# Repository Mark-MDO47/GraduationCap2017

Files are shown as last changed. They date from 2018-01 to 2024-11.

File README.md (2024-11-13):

# GraduationCap2017
Graduation Cap Lights for my identical twin girls "I" and "T" - 2017-12-09<br>

**Table Of Contents**
* [Top](#graduationcap2017 "Top")
* [Photos and Videos](#photos-and-videos "Photos and Videos")
* [General Description](#general-description "General Description")
  * [Details of Design - Arduino Code](#details-of-design-\--arduino-code "Details of Design - Arduino Code")
  * [Details of Design - Schematics and etc.](#details-of-design-\--schematics-and-etc "Details of Design - Schematics and etc.")
  * [Details of Design - WS2812B LEDs](#details-of-design-\--ws2812b-leds "Details of Design - WS2812B LEDs")
  * [Details of Design - Keep the Wires Cool!](#details-of-design-\--keep-the-wires-cool "Details of Design - Keep the Wires Cool!")
  * [Details of Design - My Favorite Pullup Resistor Package](#details-of-design-\--my-favorite-pullup-resistor-package "Details of Design - My Favorite Pullup Resistor Package")

## Photos and Videos
[Top](#graduationcap2017 "Top")<br>
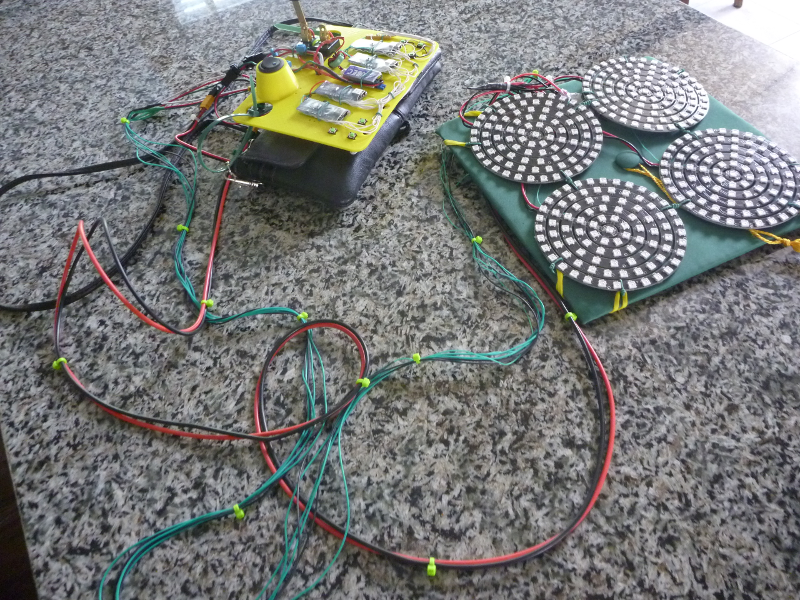
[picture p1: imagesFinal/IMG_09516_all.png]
Finished version of Graduation Cap; batteries inside purses

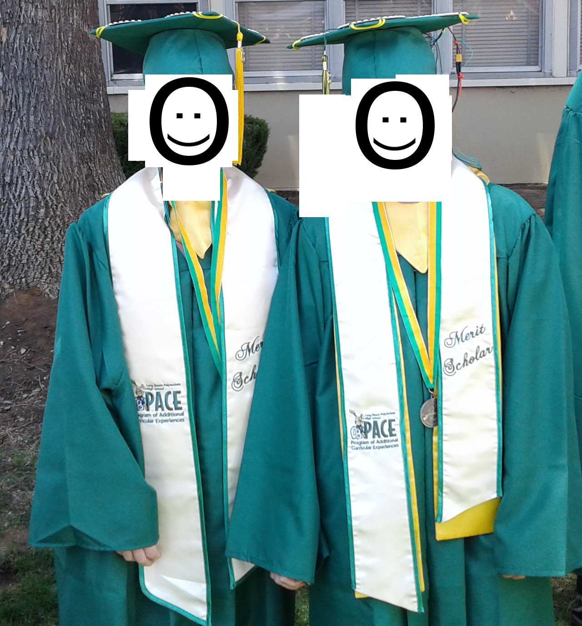
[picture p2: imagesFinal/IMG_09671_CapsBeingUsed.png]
Graduation Caps just before use


A few videos of the graduation cap:<br>
tour - https://youtu.be/3sHkcpifI_0 - Walkthrough of Graduation Cap<br>
Start plus the Down-the-Drain and Haunt patterns - https://youtu.be/SVAW7-W8W8M - my made-up patterns<br>
Radar - https://youtu.be/vZpsce-uMeo - my made-up pattern<br>
Circles - https://youtu.be/3rO7r-2uvlA - my made-up pattern<br>
Kriegsman Fire - https://youtu.be/K7lBy67Jgzw - Mark Kriegsman's Fire2012 with Palette<br>
Kriegsman Juggle - https://youtu.be/Ot5dQEGN8O8 - Mark Kriegsman's Juggle<br>
Kriegsman BPM - https://youtu.be/0liTM4aSAok - Mark Kriegsman's BPM<br>
Pictures and pointers to videos of Graduation cap are in the /FirstCap and imagesFinal directories<br>

## General Description
[Top](#graduationcap2017 "Top")<br>
The graduation cap electronics uses four Arduino Nanos with USB mini-B connector<br>
- example: https://www.aliexpress.us/item/2255800392785775.html ***Select Mini-USB Welding***<br>
  - V3.0 ATmega328P 5V 16M CH340 Compatible to Arduino Nano V3<br>
  - 32Kbyte Flash (program storage), 2Kbyte SRAM, 1Kbyte EEPROM<br>
  - http://www.mouser.com/pdfdocs/Gravitech_Arduino_Nano3_0.pdf<br>
  - http://www.pighixxx.com/test/pinouts/boards/nano.pdf<br>

Uses 93 Leds WS2812B 5050 RGB LED Ring Lamp Light with Integrated Drivers<br>
- https://www.amazon.com/WESIRI-WS2812B-Individually-Addressable-Controller/dp/B083W44B8N<br>

Kudos to Daniel Garcia and Mark Kriegsman for the FANTASTIC Arduino FastLED library and examples!!!<br>
  https://github.com/FastLED/FastLED<br>
  https://github.com/FastLED/FastLED/blob/master/examples<br>

The Arduino pattern code here is pretty much done from scratch by me using the FastLED library.<br>
I also tried a few items from Mark Kriegsman's classic DemoReel100.ino https://github.com/FastLED/FastLED/tree/master/examples/DemoReel100<br>
Okay, I succumbed and added in Mark's beautiful Fire2012withPalette https://github.com/FastLED/FastLED/tree/master/examples/Fire2012WithPalette<br>
At this point the patterns are about 50-50 mine and Mark Kriegsman<br>

### Details of Design - Arduino Code
[Top](#graduationcap2017 "Top")<br>
The Arduino code can be found here:<br>
https://github.com/Mark-MDO47/GraduationCap2017/tree/master/ArduinoCode/GradCap

### Details of Design - Schematics and etc.
[Top](#graduationcap2017 "Top")<br>
Schematic and other build information can be found here<br>
* https://github.com/Mark-MDO47/GraduationCap2017/blob/master/buildInfo/README.md

### Details of Design - WS2812B LEDs
[Top](#graduationcap2017 "Top")<br>
Here is a (somewhat) spec on the WS2812b LEDs<br>
  https://cdn-shop.adafruit.com/datasheets/WS2812B.pdf<br>
Here is a Worldsemi WS2812B document for download: <br>
  http://www.world-semi.com/solution/list-4-1.html#108<br>

### Details of Design - Keep the Wires Cool!
[Top](#graduationcap2017 "Top")<br>
Calculating wire size (Google for instance wire gauge ampacity 5v dc):<br>
  https://electronics.stackexchange.com/questions/148648/minimum-wire-gauge-for-5-volt-5-amp-system<br>

These LEDs use power that adds up. Can use this to estimate the power<br>

   http://fastled.io/docs/3.1/group___power.html<br>

     calculate_max_brightness_for_power_vmA(lots of parameters)
     
   https://github.com/FastLED/FastLED/blob/master/power_mgt.cpp<br>

     static const uint8_t gRed_mW   = 16 * 5; // 16mA @ 5v = 80mW
     static const uint8_t gGreen_mW = 11 * 5; // 11mA @ 5v = 55mW
     static const uint8_t gBlue_mW  = 15 * 5; // 15mA @ 5v = 75mW
     static const uint8_t gDark_mW  =  1 * 5; //  1mA @ 5v =  5mW
  
   about 42 milliamps per LED at max brightness WHITE<br>

### Details of Design - My Favorite Pullup Resistor Package
[Top](#graduationcap2017 "Top")<br>
Using DigiKey (https://digikey.com) 4610X-AP1-103LFCT-ND RES ARRAY 9 RES 10K OHM 10SIP<br>
   This way I have one component for all the 10K pull-up resistors I need<br>

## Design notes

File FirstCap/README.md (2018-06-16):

FirstGradCap.mp4 - video of cap with all four LED disks doing same pattern

LED_Disk_soldering.JPG            - how to wire the LED Disk<br>
LED_Disk_soldering_closeup.JPG    - how to wire the LED Disk - closeup<br>
GradCapWithDisks_FirstAttempt.JPG - start of putting the Cap together<br>

P1010498.JPG - start of wiring - finished 3 of 6 buttons - that is enough!!!<br>
P1010499.JPG - different view<br>
P1010500.JPG - different view<br>
<br>
P1010501.JPG - switch for LED power - uses 5.5Kohm to ground for internal light<br>
P1010502.JPG - detail of switch for LED power<br>
P1010503.JPG - added some connectors, made mistake for Arduino power-in (missed knife switch). Note attempting knots for strain relief.<br>
P1010506.JPG - all Arduinos wired & 3 buttons. Using cable tie for strain relief, color coded cable tie to identify connectors. Still error for Arduino power.<br>
P1010507.JPG - backside in process<br>
P1010508.JPG - starting on 2nd controller board, still have not noticed Arduino power error.<br>
P1010509.JPG - closeup 2nd controller board showing Arduino Nano soldering<br>
P1010510.JPG - closeup Arduino Nano soldering<br>
P1010511.JPG - closeup Arduino Nano soldering<br>
P1010512.JPG - closeup Arduino Nano soldering complete<br>
P1010513.JPG - closeup Arduino Nano soldering complete reverse side<br>

Videos of the graduation cap:<br>
tour  - https://youtu.be/3sHkcpifI_0 - Walkthrough of Graduation Cap<br>
Start plus the Down-the-Drain and Haunt patterns - https://youtu.be/SVAW7-W8W8M - my made-up patterns<br>
Radar - https://youtu.be/vZpsce-uMeo - my made-up pattern<br>
Circles - https://youtu.be/3rO7r-2uvlA - my made-up pattern<br>
Kriegsman Fire - https://youtu.be/K7lBy67Jgzw - Mark Kriegsman's Fire2012 with Palette<br>
Kriegsman Juggle - https://youtu.be/Ot5dQEGN8O8 - Mark Kriegsman's Juggle<br>
Kriegsman BPM - https://youtu.be/0liTM4aSAok - Mark Kriegsman's BPM<br>

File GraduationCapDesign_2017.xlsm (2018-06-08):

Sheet: CapDesign
Final

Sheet: PictureRing
Mokungit 93 Leds WS2812B WS2812 5050 RGB LED Ring Lamp Light with Integrated Drivers
https://smile.amazon.com/gp/product/B01EUAKLT0/ref=oh_aui_detailpage_o01_s00?ie=UTF8&psc=1
 | 2812b 5 volt
 | LED count | diameter
 | 32 | 110
 | 24 | 90
 | 16 | 70
 | 12 | 50
 | 8 | 30
 | 1 | N/A
 | 93 | total
 | Question: What are the dimensions of the rings?
 | Answer: My digital caliper says:
 | 32 led ring: 111.8 mm diameter
 | 24 led ring: 91.8 mm diameter… see more
 | ratio |  | part | 2 | 3 | 4 | 5 | 6 | 7 | 8
 | 4 to 3 | 8 to 6 |  | 16 | 10.66666667 | 8 | 6.4 | 5.333333333 | 4.571428571 | 4
 | 3 to 2 | 6 to 4 |  | 12 | 8 | 6 | 4.8 | 4 | 3.428571429 | 3
 |  | 4 to 3 |  | 8 | 5.333333333 | 4 | 3.2 | 2.666666667 | 2.285714286 | 2
 |  | 3 to 2 |  | 6 | 4 | 3 | 2.4 | 2 | 1.714285714 | 1.5
 |  |  |  | 4 | 2.666666667 | 2 | 1.6 | 1.333333333 | 1.142857143 | 1
 |  |  | outside-to-outside outer hole to diag outer hole |  |  |  | outside-to-outside outer hole to adjacent outer hole |  |  |  |  |  | hole diameter
 |  |  | 110.66 |  |  |  | 85.62 |  | 70.57 |  |  |  | 1.45
 |  |  | 110.45 |  |  |  | 86.01 |  | 70.83 |  |  |  | 1.54
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

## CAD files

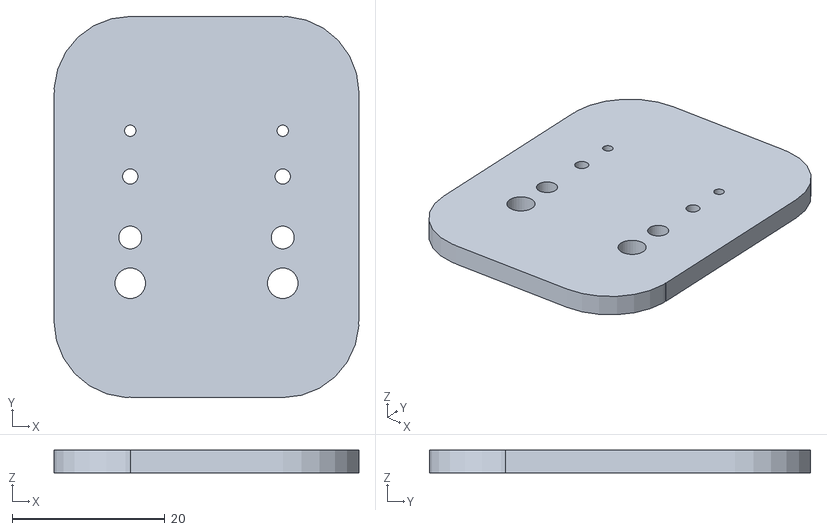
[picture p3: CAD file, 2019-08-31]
3D-Print/zzzTest.stl
40.0 x 50.0 x 3.00

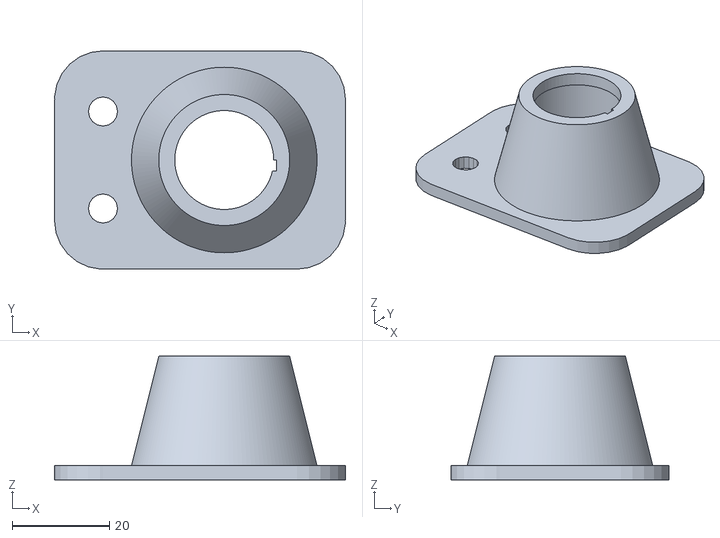
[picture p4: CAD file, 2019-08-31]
3D-Print/aaaTest.stl
60.0 x 45.0 x 25.5

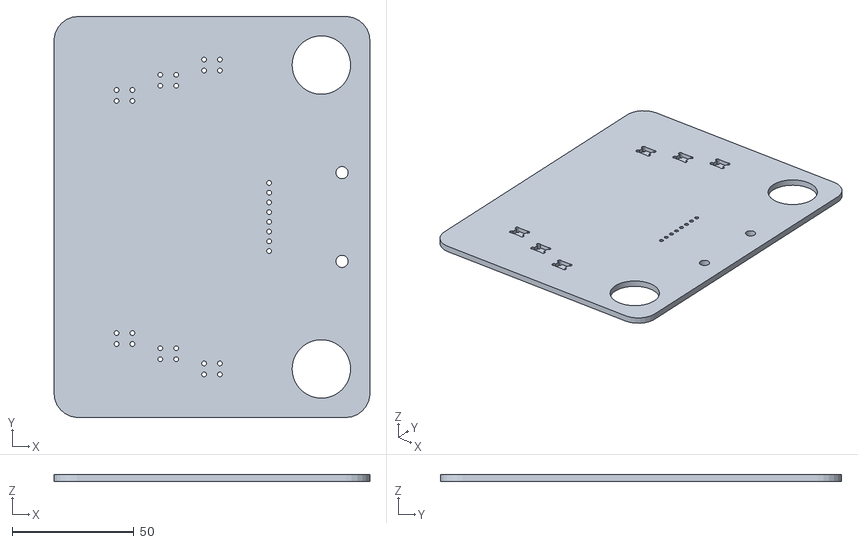
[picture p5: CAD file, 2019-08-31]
3D-Print/GradCapBracket.stl
130.0 x 165.0 x 3.00

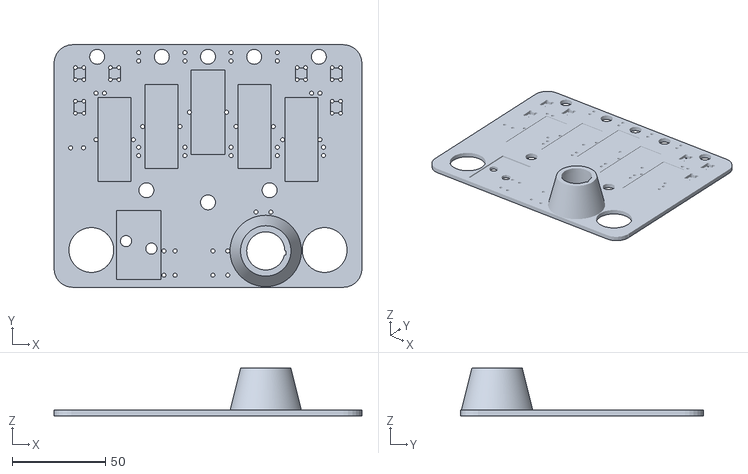
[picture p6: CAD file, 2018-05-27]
3D-Print/GradCapPurseHanger.stl
165.0 x 130.0 x 25.5

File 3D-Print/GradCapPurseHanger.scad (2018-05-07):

// Graduation Cap Lights for my identical twin girls high school graduation - 2017-12-09
// Mark Olson
// https://github.com/Mark-MDO47/GraduationCap2017
// 
// uses Mokungit 93 Leds WS2812B WS2812 5050 RGB LED Ring Lamp Light with Integrated Drivers
//   https://smile.amazon.com/gp/product/B01EUAKLT0/ref=oh_aui_detailpage_o01_s00?ie=UTF8&psc=1
// Kudos to Daniel Garcia and Mark Kriegsman for the FANTASTIC Arduino FastLED library and examples!!!
//   https://github.com/FastLED/FastLED
//   https://github.com/FastLED/FastLED/blob/master/examples/Fire2012WithPalette/Fire2012WithPalette.ino
// Some mods were made to the Arduino code by me to adapt to circular rings and also to add some patterns like spinners

// VERY handy routine from WarrantyVoider, published May 26, 2011
use<roundCornersCube.scad> // http://www.thingiverse.com/thing:8812

/*
    -----------------------------------------------------------
                 Round Corners Cube (Extruded)
      roundCornersCube(x,y,z,r) Where: (rounding done x and x corners)
         - x = Xdir width
         - y = Ydir width
         - z = Height of the cube
         - r = Rounding radius
      Example: roundCornerCube(10,10,2,1);
     *Some times it's needed to use F6 to see good results!
 	 -----------------------------------------------------------
*/
//
// This is the purse-hanger portion of the graduation cap project
//    The purse will carry the batteries, the purse-hanger has the
//    electronics, buttons, and connectors to the cables going to
//    the cap itself.
//
// I purse:  145 mm from strap-strap centerlines - 
//                straps <= 8 mm thick
//                about 190 mm horizontal
//                about 135 mm vertical
// T purse: 219 mm from strap-strap  - 8.6 inches
//                straps attached with metal D-ring
//                10 mm inner diameter D-ring
//                about 225 mm horizontal
//                about 110 mm vertical
//
// note: longest dimension on my table is 7 inches. 6.5 inches is about 165 millimeter

dsply_arduino = false;
color_arduino = "aqua";

dsply_ubec = false;
color_ubec = "red";

dsply_switch = false;
color_switch = "blue";

dsply_rsstr = false;
color_rsstr = "brown";

color_atch = "purple"; // wire attachment points

prjhngr_side  = 165; // from purse-strap to purse-strap
prjhngr_elect = 130; // width needed for electronics
prjhng_hook_width = 48; // hook stick width
prjhng_hook_length = 90; // hook stick length
prjhng_hook_inner_radius = 12; // hook

prjhng_hole_inner_radius = 12;
prjhng_hole_outer_radius = 20;

prjhng_thickness_frame = 3;
prjhng_thickness_cutout = 4;

// push buttons for choosing LED pattern
prjhng_btn_deep = prjhng_thickness_frame;
prjhng_btn_square = 6;
prjhng_btn_landing_long = 6.5;
prjhng_btn_landing_short = 4.5;
prjhng_btn_outer_long = 7.75; // includes bending of legs
// button location
prjhng_btn_fromside = (prjhngr_side/2-prjhng_hole_outer_radius);
prjhng_btn_fromhole = (prjhngr_elect/2-prjhng_hole_outer_radius);

// Arduino for controling LEDs
prjhngr_ardu_long   = 45;
prjhngr_ardu_short  = 17.6;
prjhngr_ardu_height = 4;
// arduino location
prjhngr_ardu_fromhole = -0.8*prjhngr_ardu_short;
prjhngr_ardu_fromhole_ary = [+1.0*prjhngr_ardu_fromhole, +1.5*prjhngr_ardu_fromhole, +1.5*prjhngr_ardu_fromhole, +1.0*prjhngr_ardu_fromhole];
prjhngr_ardu_fromside_ary = [-0.8*prjhng_btn_fromside, -0.4*prjhng_btn_fromside, +0.4*prjhng_btn_fromside, +0.8*prjhng_btn_fromside];

// UBEC for translating Arduino power
prjhngr_ubec_long   = 45.5;
prjhngr_ubec_short  = 18;
prjhngr_ubec_height = 4;
// arduino location
prjhngr_ubec_fromhole = -1.6*prjhngr_ubec_short;

// rocker power switch for LED power
// comments say need 13/16 inch hole or 0.8125 in or 20.6375 mm or 10.32 mm rad.
// manufacturer says "All you need is a 3/4" hole and the switch will sit in nicely"
//    0.75 in = 19.05 mm
// SparkFun says "They mount into a 20.2mm diameter hole"
// I measure 20.3 mm diam or 10.15 mm rad and that over a little knob it has
//   my measurement works quite well at 10.2
prjhngr_rokr_rad =       10.2;
prjhngr_rokr_height =    18.3;
prjhngr_rokr_lip_catch =  0.8;
prjhngr_rokr_lip_height = 2.4;
prjhngr_rokr_lip_rad =   11.5;
prjhngr_rokr_key_width =  2.3;
prjhngr_rokr_key_bump  =  0.6;
prjhngr_rokr_fromhole =   0.7*prjhngr_elect/2;
prjhngr_rokr_fromside =   0.375*prjhngr_side/2;
// rocker mount - to keep all high points on one side
prjhngr_rokrmnt_height = 24.0;
prjhngr_rokrmnt_btmrad = prjhngr_rokr_lip_rad+8;
prjhngr_rokrmnt_toprad = prjhngr_rokr_lip_rad+2;

// knife switch for arduino power
prjhngr_knif_outlong =         37.0; // y direction
prjhngr_knif_outshort =        24.0;
prjhngr_knif_outhigh =          7.5;
prjhngr_knif_ofsthol_short_s =  5.2;
prjhngr_knif_ofsthol_short_l = 18.8;
prjhngr_knif_ofsthol_long_s =  16.5;
prjhngr_knif_ofsthol_long_l =  20.5;
prjhngr_knif_cntrhol_short_s = 12.0;
prjhngr_knif_cntrhol_short_l = 12.0;
prjhngr_knif_cntrhol_long_s =   8.1;
prjhngr_knif_cntrhol_long_l =  28.9;
prjhngr_knif_knob_ovrhng =     13.7;
prjhngr_knif_knob_width =       4.7;
prjhngr_knif_fromhole =   0.65*prjhngr_elect/2;
prjhngr_knif_fromside =   0.45*prjhngr_side/2;
// holes for potential screws for knife switch
prjhngr_knif_ofsthol_rad = 3.0; // this works for ziptie attachment too
prjhngr_knif_cntrhol_rad = 3.0;
prjhngr_knif_ofsthol =  true;
prjhngr_knif_cntrhol =  false;

// 10K pullup multi-resistor
prjhngr_rsstr_short =     4.9;
prjhngr_rsstr_long =     25.2;
prjhngr_rsstr_high =      2.2;
prjhngr_rsstr_fromhole = -0.15*prjhngr_elect/2;
prjhngr_rsstr_fromside =  -0.85*prjhngr_side/2;

// wiring attachment points - width
prjhngr_atch_pwrled_short  = 6.0; // both LED power (under) and Arduino data lines (over)
prjhngr_atch_pwrled_fromhole_ary = [0.9*prjhngr_elect/2, 0.7*prjhngr_elect/2, 0.38*prjhngr_elect/2];
prjhngr_atch_pwrled_fromside_ary = [0.08*prjhngr_side/2, 0.08*prjhngr_side/2, 0.36*prjhngr_side/2];
prjhngr_atch_pwrardu_short = 4.0;
prjhngr_atch_pwrardu_fromhole_ary = [0.9*prjhngr_elect/2,  0.7*prjhngr_elect/2];
prjhngr_atch_pwrardu_fromside_ary = [-0.25*prjhngr_side/2, -0.25*prjhngr_side/2];
prjhngr_atch_sgnlgnd_short = 2.5;
prjhngr_sgnlgnd_bus1_fromhole = -0.12*prjhngr_elect/2; // bus 1 is in middle of board
prjhngr_sgnlgnd_bus2_fromhole = -0.90*prjhngr_elect/2; // bus 2 is near bottom of board
prjhngr_atch_sgnlgnd_fromhole_ary = [-0.60*prjhngr_elect/2, -0.60*prjhngr_elect/2,
    prjhngr_sgnlgnd_bus1_fromhole, prjhngr_sgnlgnd_bus1_fromhole,
    prjhngr_sgnlgnd_bus1_fromhole, prjhngr_sgnlgnd_bus1_fromhole, prjhngr_sgnlgnd_bus1_fromhole,
    prjhngr_sgnlgnd_bus2_fromhole, prjhngr_sgnlgnd_bus2_fromhole,
    prjhngr_sgnlgnd_bus2_fromhole, prjhngr_sgnlgnd_bus2_fromhole];
prjhngr_atch_sgnlgnd_fromside_ary = [-0.70*prjhngr_side/2,  +0.70*prjhngr_side/2,
    -0.45*prjhngr_side/2, -0.15*prjhngr_side/2,
    +0.15*prjhngr_side/2, +0.45*prjhngr_side/2, +0.75*prjhngr_side/2,
    -0.45*prjhngr_side/2, -0.15*prjhngr_side/2,
    +0.15*prjhngr_side/2, +0.45*prjhngr_side/2];

prjhngr_thruwire_rad = 4;
prjhngr_thruwire_fromhole_ary = [+0.30*prjhngr_elect/2, -0.90*prjhngr_elect/2,
    -0.90*prjhngr_elect/2, -0.90*prjhngr_elect/2,
    -0.90*prjhngr_elect/2, -0.90*prjhngr_elect/2,
    +0.20*prjhngr_elect/2, +0.20*prjhngr_elect/2];
prjhngr_thruwire_fromside_ary = [ 0, 0,
    -0.72*prjhngr_side/2,  +0.72*prjhngr_side/2,
    -0.30*prjhngr_side/2,  +0.30*prjhngr_side/2,
    -0.4*prjhngr_side/2,  +0.4*prjhngr_side/2];
prjhngr_ziptie_rad = 1.1; // 3 allows actual zip-tie, 1.1 just barely fits wire

module aaaTest() { // aaaTest - test of holes for rokr and ziptie
    rotate ([0,0,-90]) difference() {
        union() {
            roundCornersCube(45,60,3, 10);
            translate([0,5,0]) prjhngr_rokrmnt();
        } // end union()
        //translate([0,5,-prjhngr_rokrmnt_height/2]) prjhngr_rokr(200);
        translate([0,5,-5]) color("green")translate([0,0,+(prjhngr_rokrmnt_height-prjhng_thickness_frame)/2])linear_extrude(height = prjhngr_rokrmnt_height-prjhng_thickness_frame, center = true, convexity = 0, twist = 0, slices = 100, scale = 1.0) circle(r=prjhngr_rokr_lip_rad,$fn=128);
        translate([+10,-20,0]) prjhngr_ziptiehole();
        translate([-10,-20,0]) prjhngr_ziptiehole();
    } // end difference()
}

module bbbTest() { // bbbTest - test of holes for knife switch
    rotate ([0,0,-90]) union() {
        difference() {
            roundCornersCube(50,40,3, 10);
            translate([0,0,-1]) prjhngr_knif();
            prjhngr_knif_holes();
        } // end union
        //prjhngr_knif();
    } // end difference
}  // end bbbTest()

module cccTest() { // cccTest - test of 10k pullup resistor and mounting holes
    rotate ([0,0,-90]) union() {
        difference() {
            roundCornersCube(50,40,3, 10);
            prjhngr_rsstr_holes();
        } // end union
        if (dsply_rsstr) prjhngr_rsstr();
    } // end difference
}  // end bbbTest()
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

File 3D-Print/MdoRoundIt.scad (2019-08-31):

module MdoRoundItOnXaxis(dim_long, hole_diam, square_width)
{
    difference() {
        translate([-dim_long/2, -square_width/2, -square_width/2]) cube([dim_long, square_width, square_width]);
        rotate([0, 90, 0]) translate([0, 0, -(dim_long+2)/2])cylinder(r=hole_diam/2,h=dim_long+2,$fn=128);
        translate([-dim_long/2-1, -square_width/2-1, -square_width-2]) cube([dim_long+2, square_width+2, square_width+2]);
    }
}   // end MdoRoundItOnXaxis()

MdoRoundItOnXaxis(100,10,15);

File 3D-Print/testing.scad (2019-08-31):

// VERY handy routine from WarrantyVoider, published May 26, 2011
use<roundCornersCube.scad> // http://www.thingiverse.com/thing:8812


kstn_jack_stretch = 0.75; // MDO mod: my keystone jacks are slightly larger or maybe my printer is different; cannot jam jacks in without some stretch

kstn_jack_length = 16.5;
kstn_jack_width = 15;

kstn_wall_height = 10;
kstn_wall_thickness = 5;

kstn_catch_overhang = 2;

kstn_small_clip_depth = kstn_catch_overhang;
kstn_big_clip_depth = kstn_catch_overhang + 2;
kstn_big_clip_clearance = 4;
kstn_small_clip_clearance = 6.5;

// MDO mod: add kstn_jack_stretch to length for my slightly larger keystone jacks
kstn_outer_length = kstn_jack_length + kstn_small_clip_depth + kstn_big_clip_depth +
                            (kstn_wall_thickness * 2) + kstn_jack_stretch;
kstn_outer_width = kstn_jack_width + (kstn_wall_thickness * 2);



// roundCornersCube(kstn_outer_length, kstn_outer_width, kstn_wall_height,2);
cube([kstn_outer_length, kstn_outer_width, kstn_wall_height]);

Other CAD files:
3D-Print/bbbTest.stl
3D-Print/roundCornersCube.scad

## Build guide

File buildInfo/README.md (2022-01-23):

# Build Info README

## Schematic

Schematic for Graduation Cap<br>
* https://github.com/Mark-MDO47/GraduationCap2017/blob/master/buildInfo/Schematic_4_Arduinos.pdf

## Signal Tracing for 4 Arduinos/LEDrings

Top view of Cap showing placement of LED Rings
* https://github.com/Mark-MDO47/GraduationCap2017/blob/master/buildInfo/CapTopView.png

Annotated photo of controller board identifying Arduino controlling each LED ring
* https://github.com/Mark-MDO47/GraduationCap2017/blob/master/buildInfo/ControllerIdentifySignal.png

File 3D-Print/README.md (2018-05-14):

NOTE:

Due to major project simplifications, the only 3D print I am using is GradCapPurseHanger.scad

Thanks!
Mark

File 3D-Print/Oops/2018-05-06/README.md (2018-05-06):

When print started there was a slight mis-registration between the first raft outline layer and the next.
It looked to be on track after that and was still looking good a few hours later.
After about 8 hours it showed signs of warping up off the bed from one corner that was hanging off the first raft outline layer (in the air)
Next morning it was a disaster.
 The raft and start of the print were pushed off the bed.
 The printer hot end was still spewing and was completely coated with plastic.
 Even the wires to the hot end were encapsulated.
 477 thru 479

Fortunately when I heated up to pull the filament out the encapsulation was brittle.
  Small manipulations made pieces that could pull off with needle-nose.
  Even the plastic around the wires came apart, though I was worried.
  484 thru 485

Additional cleanup makes it look almost like before. Will have to see if it works
  489 thru 491

The partial print was usable to do a fit-check of some parts.
  493 thru 495

Hmm - comment of "that doesn't look good!!!" gets turned by bash into "that doesn't look goodgit status!".
A bit of an information leak there... not too bad this time.

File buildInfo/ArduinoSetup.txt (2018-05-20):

Arduino Uno  - Board "Arduino/Genuino Uno"
Arduino Nano - Board "Arduino Nano"  - use Old Bootloader

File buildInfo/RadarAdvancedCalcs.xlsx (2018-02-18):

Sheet: Sheet1
const uint8_t leds_per_ring[NUM_RINGS_PER_DISK] = { 32, 24, 16, 12, 8, 1 };
const uint8_t leds_per_ringqrtr[NUM_RINGS_PER_DISK] = { 8, 6, 4, 3, 2, 1 };
const uint8_t start_per_ring[NUM_RINGS_PER_DISK] = { 0, 32, 56, 72, 84, 92 };
const uint8_t radar_adv_per_LED_per_ring[NUM_RINGS_PER_DISK] = { 0, 192, 128, 96, 64, 0 };
 |  |  |  |  | tmp_calc for this_ring |  |  |  | theLED for this ring |  |  |  | 2nd tmp_calc for this_ring
 | tmp_idx | radar_adv_per_LED_per_ring | start_per_ring | leds_per_ring | 1 | 2 | 3 | 4 | 1 | 2 | 3 | 4 | 1 | 2 | 3 | 4
 | 0 | 0 | 0 | 32 | 0 | 0 | 0 | 0 | 32 | 56 | 72 | 84 | 55 | 71 | 83 | 91
 | 1 | 192 | 32 | 24 | 0 | 0 | 0 | 0 | 32 | 56 | 72 | 84 | 55 | 71 | 83 | 91
 | 2 | 128 | 56 | 16 | 1 | 1 | 0 | 0 | 33 | 57 | 72 | 84 | 32 | 56 | 83 | 91
 | 3 | 96 | 72 | 12 | 2 | 1 | 1 | 0 | 34 | 57 | 73 | 84 | 33 | 56 | 72 | 91
 | 4 | 64 | 84 | 8 | 3 | 2 | 1 | 1 | 35 | 58 | 73 | 85 | 34 | 57 | 72 | 84
 | 5 | 0 | 92 | 1 | 3 | 2 | 1 | 1 | 35 | 58 | 73 | 85 | 34 | 57 | 72 | 84
 | 6 |  |  |  | 4 | 3 | 2 | 1 | 36 | 59 | 74 | 85 | 35 | 58 | 73 | 84
 | 7 |  |  |  | 5 | 3 | 2 | 1 | 37 | 59 | 74 | 85 | 36 | 58 | 73 | 84
 | 8 |  |  |  | 6 | 4 | 3 | 2 | 38 | 60 | 75 | 86 | 37 | 59 | 74 | 85
 | 9 |  |  |  | 6 | 4 | 3 | 2 | 38 | 60 | 75 | 86 | 37 | 59 | 74 | 85
 | 10 |  |  |  | 7 | 5 | 3 | 2 | 39 | 61 | 75 | 86 | 38 | 60 | 74 | 85
 | 11 |  |  |  | 8 | 5 | 4 | 2 | 40 | 61 | 76 | 86 | 39 | 60 | 75 | 85
 | 12 |  |  |  | 9 | 6 | 4 | 3 | 41 | 62 | 76 | 87 | 40 | 61 | 75 | 86
 | 13 |  |  |  | 9 | 6 | 4 | 3 | 41 | 62 | 76 | 87 | 40 | 61 | 75 | 86
 | 14 |  |  |  | 10 | 7 | 5 | 3 | 42 | 63 | 77 | 87 | 41 | 62 | 76 | 86
 | 15 |  |  |  | 11 | 7 | 5 | 3 | 43 | 63 | 77 | 87 | 42 | 62 | 76 | 86
 | 16 |  |  |  | 12 | 8 | 6 | 4 | 44 | 64 | 78 | 88 | 43 | 63 | 77 | 87
 | 17 |  |  |  | 12 | 8 | 6 | 4 | 44 | 64 | 78 | 88 | 43 | 63 | 77 | 87
 | 18 |  |  |  | 13 | 9 | 6 | 4 | 45 | 65 | 78 | 88 | 44 | 64 | 77 | 87
 | 19 |  |  |  | 14 | 9 | 7 | 4 | 46 | 65 | 79 | 88 | 45 | 64 | 78 | 87
 | 20 |  |  |  | 15 | 10 | 7 | 5 | 47 | 66 | 79 | 89 | 46 | 65 | 78 | 88
 | 21 |  |  |  | 15 | 10 | 7 | 5 | 47 | 66 | 79 | 89 | 46 | 65 | 78 | 88
 | 22 |  |  |  | 16 | 11 | 8 | 5 | 48 | 67 | 80 | 89 | 47 | 66 | 79 | 88
 | 23 |  |  |  | 17 | 11 | 8 | 5 | 49 | 67 | 80 | 89 | 48 | 66 | 79 | 88
 | 24 |  |  |  | 18 | 12 | 9 | 6 | 50 | 68 | 81 | 90 | 49 | 67 | 80 | 89
 | 25 |  |  |  | 18 | 12 | 9 | 6 | 50 | 68 | 81 | 90 | 49 | 67 | 80 | 89
 | 26 |  |  |  | 19 | 13 | 9 | 6 | 51 | 69 | 81 | 90 | 50 | 68 | 80 | 89
 | 27 |  |  |  | 20 | 13 | 10 | 6 | 52 | 69 | 82 | 90 | 51 | 68 | 81 | 89
 | 28 |  |  |  | 21 | 14 | 10 | 7 | 53 | 70 | 82 | 91 | 52 | 69 | 81 | 90
 | 29 |  |  |  | 21 | 14 | 10 | 7 | 53 | 70 | 82 | 91 | 52 | 69 | 81 | 90
 | 30 |  |  |  | 22 | 15 | 11 | 7 | 54 | 71 | 83 | 91 | 53 | 70 | 82 | 90
 | 31 |  |  |  | 23 | 15 | 11 | 7 | 55 | 71 | 83 | 91 | 54 | 70 | 82 | 90
sed "s/, /\$\$\$\$ /g" GradCap.ino | sed "s/^ /,/" | sed "s/, /,,/" | sed "s/, /,,/" | sed "s/, /,,/" | sed "s/, /,,/" | sed "s/, /,,/" | sed "s/, /,,/" > mdo.csv
else if ((STEP2_RADAR_FROM_SHDW1 == this_ptrn_token) || (STEP2_RADAR_XRAY_SHDW1 == this_ptrn_token)) {
 | uint16_t tmp_calc;
 | DEBUG_PRINTLN(F(" ...processing STEP2_RADAR_FROM_SHDW1 and friends; this_ptrn_token: "))
 | DEBUG_PRINT((int16_t) this_ptrn_token)
 | if (STEP2_RADAR_FROM_SHDW1 == this_ptrn_token) { // clear radar_xray_bitmask
 |  | radar_xray_bitmask[0] = radar_xray_bitmask[1] = radar_xray_bitmask[2] = 0;
 | } // end if need to clear bitmask for X-Ray cells
 | DEBUG_PRINTLN(F(" ... Radar Loop"))
 | for (tmp_idx = 0; tmp_idx < leds_per_ring[0]; tmp_idx++) {
 |  | // tmp_idx is the LED index on the outer ring, from 0 to 31 inclusive
 |  | // STEP2_RADAR_XRAY_SHDW1 X-Ray foreground color; STEP2_RADAR_FROM_SHDW1 does not
 |  | // First we fade previously drawn LEDs.
 |  | // If STEP2_RADAR_FROM_SHDW1: they all fade uniformly because we cleared radar_xray_bitmask
 |  | // If STEP2_RADAR_XRAY_SHDW1: the X-ray LEDs fade slower than the others
 |  | bitmsk32 = 1; // used to pick bit within radar_xray_bitmask
 |  | idx_bitmsk32 = 0; // location in radar_xray_bitmask
 |  | for (theLED = 0; theLED < NUM_LEDS_PER_DISK; theLED++){
 |  |  | if (0 != (radar_xray_bitmask[idx_bitmsk32] & bitmsk32)) { led_display[TARGET_DSPLAY+theLED].fadeToBlackBy(32); }
 |  |  | else { led_display[TARGET_DSPLAY+theLED].fadeToBlackBy(128); }
 |  |  | bitmsk32 <<= 1;
 |  |  | if (0 == bitmsk32) {
 |  |  |  | idx_bitmsk32 += 1;
 |  |  |  | bitmsk32 = 1;
 |  |  | } // end if need to cross bitmsk32 boundary
 |  | } // end loop to fade all previously drawn LEDs
 |  | // Next we draw the red line using the outer LED as a guide.
 |  | // For each ring (except center) we put a version of what was in SHDW1 previous to the red line we just drew.
 |  | // Outer and center rings are the simplest cases; do them first
 |  | led_display[TARGET_DSPLAY+NUM_LEDS_PER_DISK-1] = CRGB::Red; // center special case - no "previous" LED
 |  | led_display[TARGET_DSPLAY+tmp_idx] = CRGB::Red; // outer ring
 |  | theLED = (tmp_idx + leds_per_ring[0] - 1) % leds_per_ring[0]; // outer ring previous LED
 |  | led_display[TARGET_DSPLAY+theLED] = led_display[TARGET_SHDW1+theLED]; // outer ring copy from SHDW1
 |  | // Red line for Outer and Center are drawn; now handle middle rings
 |  | for (this_ring = 1; this_ring < NUM_RINGS_PER_DISK-1; this_ring++) {
 |  |  | // currently we do a trailing inner ring based on first LED that would have any fractional brightness
 |  |  | // first draw the red line of the radar sweep
 |  |  | tmp_calc = (uint16_t)radar_adv_per_LED_per_ring[this_ring] * tmp_idx / 256; // not same as above - / 256
 |  |  | theLED = tmp_calc + start_per_ring[this_ring]; // this is the lowest LED idx this ring
 |  |  | led_display[TARGET_DSPLAY+theLED] = CRGB::Red;
 |  |  | // now draw just behind it (where previous red line was) with contents of shadow1
 |  |  | // inner rings move slower so we start them at a lower light level using blend
 |  |  | tmp_calc = (tmp_calc + leds_per_ring[this_ring] - 1) % leds_per_ring[this_ring] + start_per_ring[this_ring]; // backup one LED
 |  |  | led_display[TARGET_DSPLAY+tmp_calc] = blend(CRGB::Black, led_display[TARGET_SHDW1+tmp_calc], leds_per_ring[this_ring]*7); // 32 leds * 8 would be 256 but our largest is 24 so no need for uint16_t
 |  | } // end RADAR for this_ring
 |  | if (doPtrnShowDwell(draw_target | led_delay | __LINE__)) return(__LINE__);
 | } // end RADAR for LED idx outer disk
} // end STEP2_RADAR_FROM_SHDW1 or STEP2_RADAR_XRAY_SHDW1 for LED idx outer disk

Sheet: Sheet2
else if ((STEP2_RADAR_FROM_SHDW1 == this_ptrn_token) || (STEP2_RADAR_FROM_SHDW1_FRGND == this_ptrn_token)) {
uint16_t tmp_calc;
DEBUG_PRINTLN(F(" ...processing STEP2_RADAR_FROM_SHDW1 and friends; this_ptrn_token: "))
DEBUG_PRINT((int16_t) this_ptrn_token)
if (STEP2_RADAR_FROM_SHDW1_FRGND == this_ptrn_token) {
DEBUG_PRINTLN(F(" ... X-Ray Exploration Loop"))
// set a bit for each cell we will "X-Ray" or fade slower
radar_xray_bitmask[0] = radar_xray_bitmask[1] = radar_xray_bitmask[2] = 0;
bitmsk32 = 1; // used to pick bit within radar_xray_bitmask
idx_bitmsk32 = 0; // location in radar_xray_bitmask
for (theLED = 0; theLED < NUM_LEDS_PER_DISK; theLED++){
if (led_display[TARGET_SHDW1+theLED] == foreground) { radar_xray_bitmask[idx_bitmsk32] |= bitmsk32; }
bitmsk32 <<= 1;
if (0 == bitmsk32) {
idx_bitmsk32 += 1;
bitmsk32 = 1;
if (idx_bitmsk32 > 2) { // should never get here
DEBUG_ERRORS_PRINTLN(F(" OVERFLOW ERROR IN STEP2_RADAR_FROM_SHDW1_FRGND loop to make bitmask for X-Ray cells"))
return(__LINE__);
} // end if something went horribly wrong
} // end if need to cross bitmsk32 boundary
// if ((0 == theLED) || ((29 <= theLED) && (34 > theLED))) { DEBUG_ERRORS_PRINT(F(" bitmsk32 info post increment. theLED=")) DEBUG_ERRORS_PRINT((uint16_t) theLED) DEBUG_ERRORS_PRINT(F(" idx_bitmsk32=")) DEBUG_ERRORS_PRINT((uint16_t) idx_bitmsk32) DEBUG_ERRORS_PRINT(F(" bitmsk32=")) DEBUG_ERRORS_PRINTLN((uint32_t) bitmsk32) } // end if debugging bitmask
} // end loop to make bitmask for X-Ray cells
// DEBUG_ERRORS_PRINT(F(" bitmsk32[0]=")) DEBUG_ERRORS_PRINT((uint32_t) radar_xray_bitmask[0]) DEBUG_ERRORS_PRINT(F(" bitmsk32[1]=")) DEBUG_ERRORS_PRINT((uint32_t) radar_xray_bitmask[1]) DEBUG_ERRORS_PRINT(F(" bitmsk32[2]=")) DEBUG_ERRORS_PRINTLN((uint32_t) radar_xray_bitmask[2])
} // end if need to make bitmask for X-Ray cells
DEBUG_PRINTLN(F(" ... Radar Loop"))
for (tmp_idx = 0; tmp_idx < leds_per_ring[0]; tmp_idx++) {
// tmp_idx is the LED index on the outer ring, from 0 to 31 inclusive
// STEP2_RADAR_FROM_SHDW1_FRGND X-Ray foreground color; STEP2_RADAR_FROM_SHDW1 does not
if (STEP2_RADAR_FROM_SHDW1 == this_ptrn_token) {
fadeToBlackBy(&led_display[TARGET_DSPLAY], NUM_LEDS_PER_DISK, 128); // last param is fade by x/256
} // end if STEP2_RADAR_FROM_SHDW1
else { // STEP2_RADAR_FROM_SHDW1_FRGND
bitmsk32 = 1; // used to pick bit within radar_xray_bitmask
idx_bitmsk32 = 0; // location in radar_xray_bitmask
for (theLED = 0; theLED < NUM_LEDS_PER_DISK; theLED++){
if (0 != (radar_xray_bitmask[idx_bitmsk32] & bitmsk32)) { led_display[TARGET_DSPLAY+theLED].fadeToBlackBy(8); } // DEBUG_ERRORS_PRINT(F(" prsrvLED=")) DEBUG_ERRORS_PRINT((uint16_t) theLED) DEBUG_ERRORS_PRINT(F(" idx_bitmsk32=")) DEBUG_ERRORS_PRINT((uint16_t) idx_bitmsk32) DEBUG_ERRORS_PRINT(F(" bitmsk32=")) DEBUG_ERRORS_PRINT((uint32_t) bitmsk32)}
else { led_display[TARGET_DSPLAY+theLED].fadeToBlackBy(128); }
bitmsk32 <<= 1;
if (0 == bitmsk32) {
idx_bitmsk32 += 1;
bitmsk32 = 1;
if (idx_bitmsk32 > 2) { // should never get here
DEBUG_ERRORS_PRINTLN(F(" OVERFLOW ERROR IN STEP2_RADAR_FROM_SHDW1_FRGND loop to use X-Ray cells"))
return(__LINE__);
} // end if something went horribly wrong
} // end if need to cross bitmsk32 boundary
} // end loop to make bitmask for X-Ray cells
} // end if STEP2_RADAR_FROM_SHDW1_FRGND
led_display[TARGET_DSPLAY+NUM_LEDS_PER_DISK-1] = CRGB::Red; // center
led_display[TARGET_DSPLAY+tmp_idx] = CRGB::Red; // outer ring
theLED = (tmp_idx + leds_per_ring[0] - 1) % leds_per_ring[0]; // backup one LED
led_display[TARGET_DSPLAY+theLED] = led_display[TARGET_SHDW1+theLED];
for (this_ring = 1; this_ring < NUM_RINGS_PER_DISK-1; this_ring++) {
// currently we do a trailing inner ring based on first LED that would have any fractional brightness
// first draw the red line of the radar sweep
tmp_calc = (uint16_t)radar_adv_per_LED_per_ring[this_ring] * tmp_idx / 256; // not same as above - / 256
theLED = tmp_calc + start_per_ring[this_ring]; // this is the lowest LED idx this ring
led_display[TARGET_DSPLAY+theLED] = CRGB::Red;
// now draw just behind it (where previous red line was) with contents of shadow1
// inner rings move slower so we start them at a lower light level using blend
tmp_calc = (tmp_calc + leds_per_ring[this_ring] - 1) % leds_per_ring[this_ring] + start_per_ring[this_ring]; // backup one LED
led_display[TARGET_DSPLAY+tmp_calc] = blend(CRGB::Black, led_display[TARGET_SHDW1+tmp_calc], leds_per_ring[this_ring]*7); // 32 leds * 8 would be 256 but our largest is 24 so no need for uint16_t
} // end RADAR for this_ring
if (doPtrnShowDwell(draw_target,led_delay,__LINE__)) return(__LINE__);
} // end RADAR for LED idx outer disk
} // end STEP2_RADAR_FROM_SHDW1 for LED idx outer disk

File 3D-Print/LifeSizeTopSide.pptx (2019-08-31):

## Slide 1

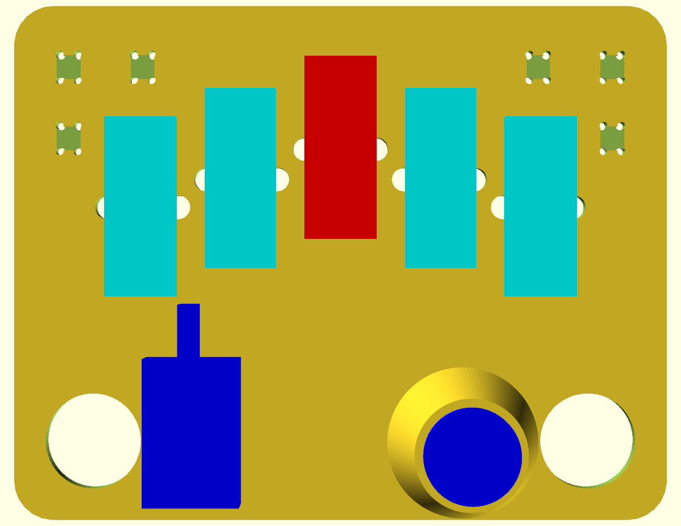
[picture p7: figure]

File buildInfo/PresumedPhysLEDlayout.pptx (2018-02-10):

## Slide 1

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
Phys

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
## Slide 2

Phys

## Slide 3

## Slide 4

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
Phys

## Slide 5

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
Phys

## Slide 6

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
Phys

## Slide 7

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
Phys

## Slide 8

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
Phys

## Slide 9

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
Phys

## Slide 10

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
Phys

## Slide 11

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
Phys

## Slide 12

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
Phys

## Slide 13

SPARE

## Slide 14

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
Phys

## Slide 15

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
Phys

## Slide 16

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
Phys

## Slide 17

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
Phys

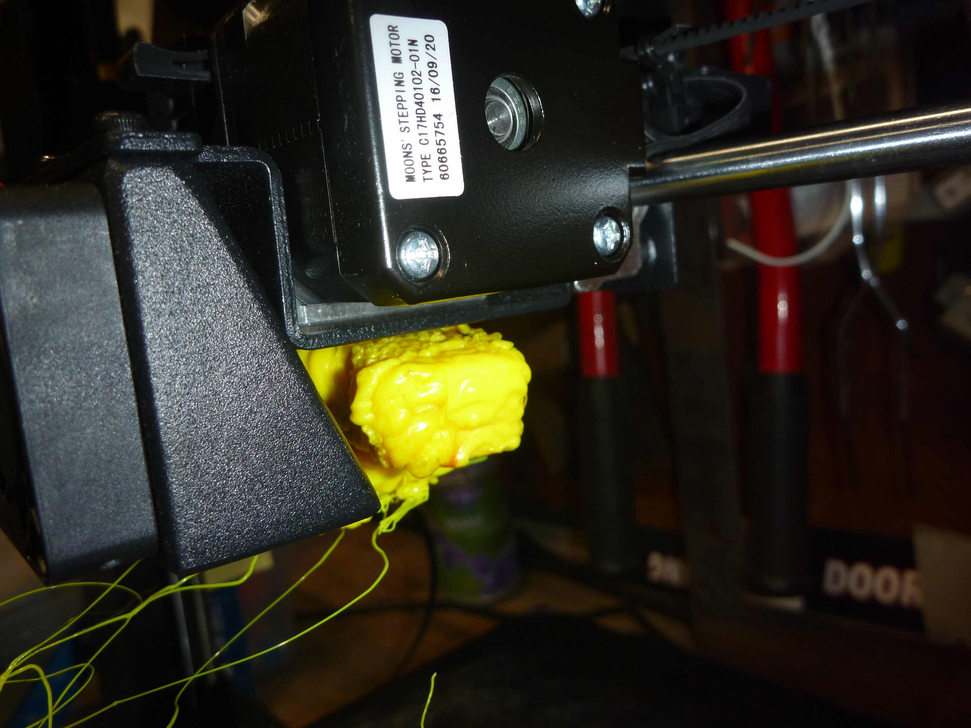
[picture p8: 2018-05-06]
3D-Print/Oops/2018-05-06/P1010479.JPG

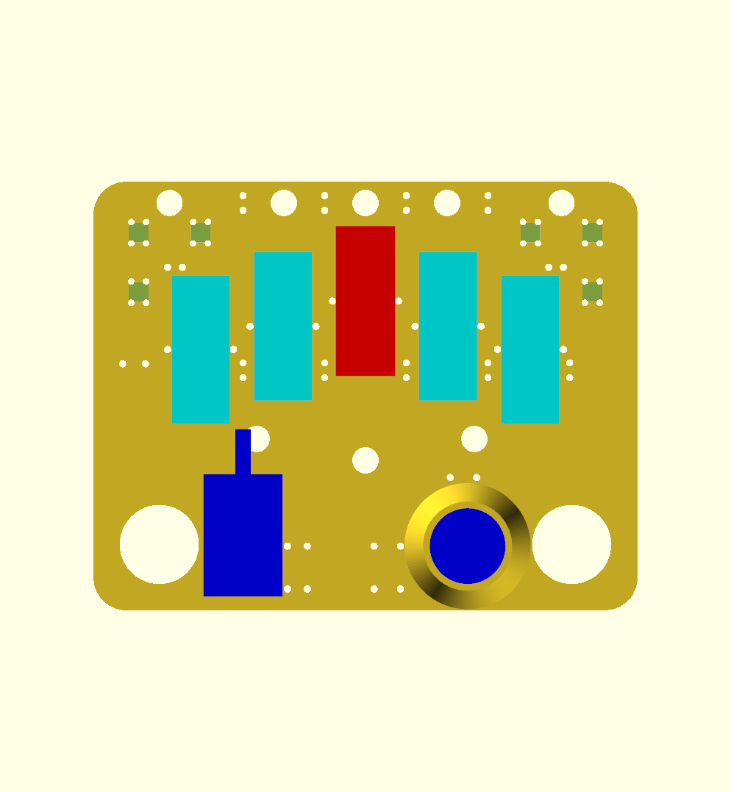
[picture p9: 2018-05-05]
3D-Print/GradCapPurseHanger_2D.png

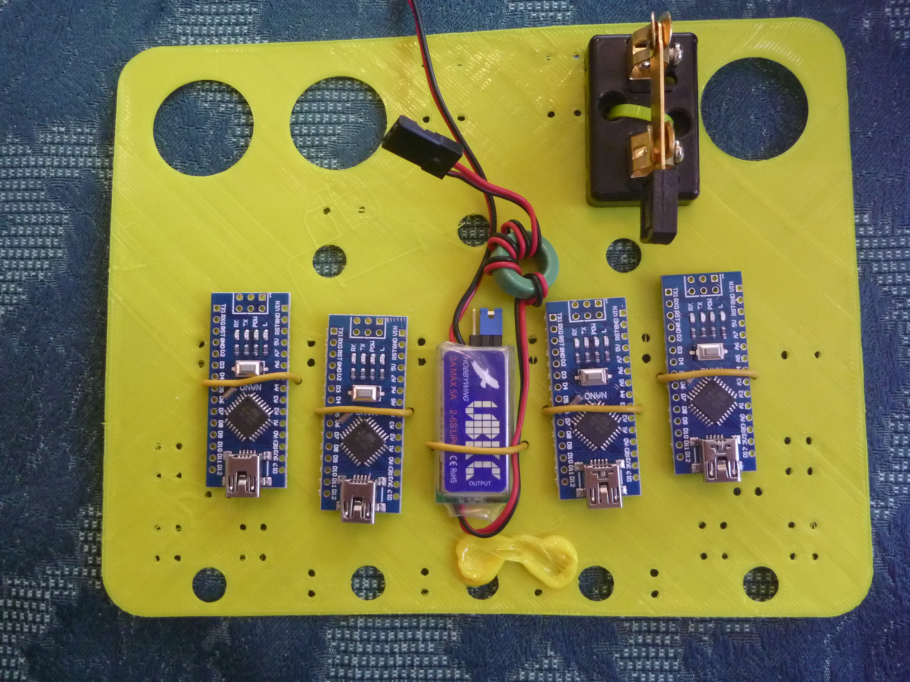
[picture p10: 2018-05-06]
3D-Print/Oops/2018-05-06/P1010494.JPG

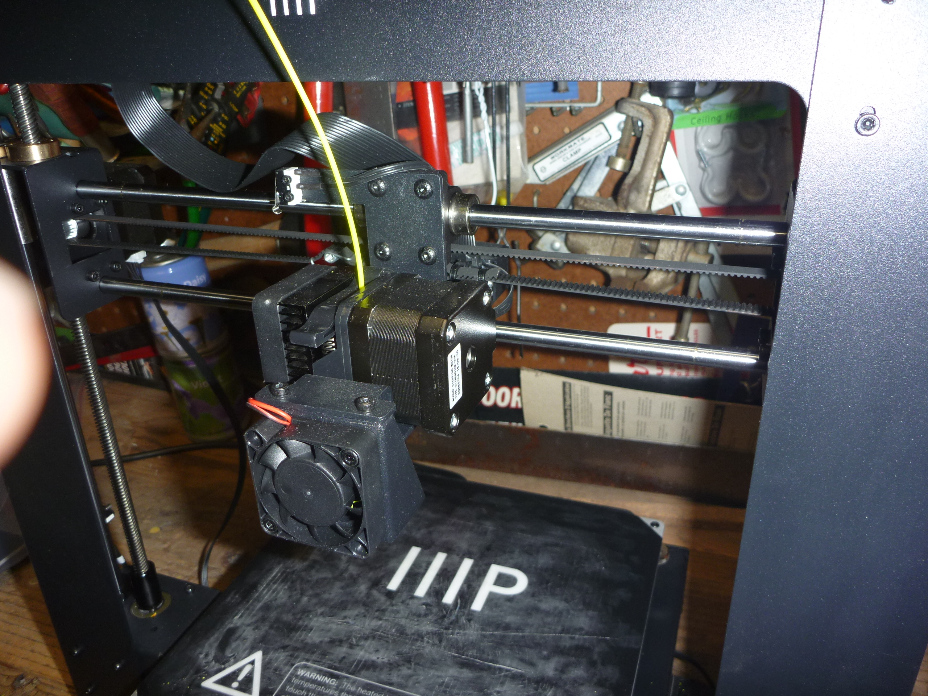
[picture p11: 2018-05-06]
3D-Print/Oops/2018-05-06/P1010491.JPG

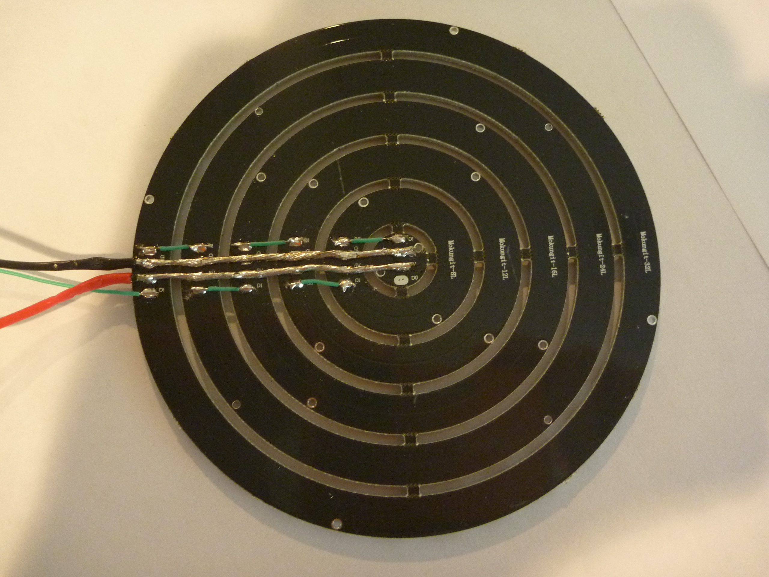
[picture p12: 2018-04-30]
FirstCap/LED_Disk_soldering.JPG

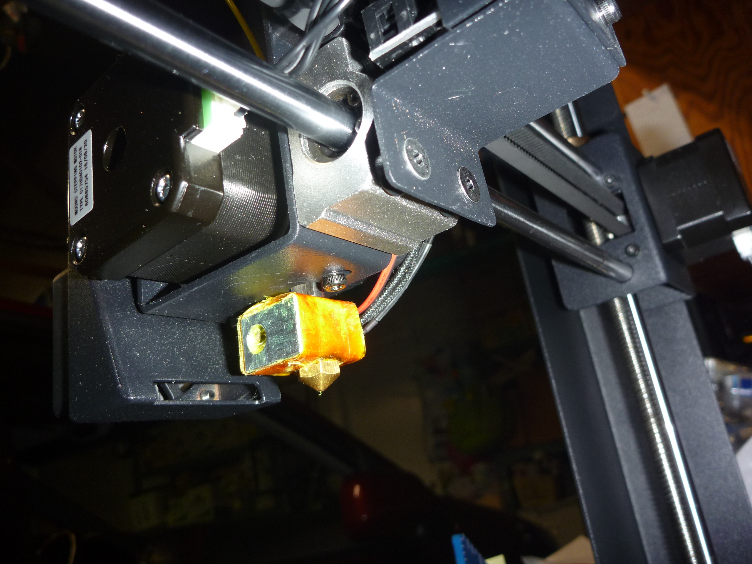
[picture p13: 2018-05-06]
3D-Print/Oops/2018-05-06/P1010490.JPG

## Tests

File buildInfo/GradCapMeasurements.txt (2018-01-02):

graduation cap
9 and 3/8 inches square (238.125 millimeter)
0.191 inch thick (4.85 millimeter)

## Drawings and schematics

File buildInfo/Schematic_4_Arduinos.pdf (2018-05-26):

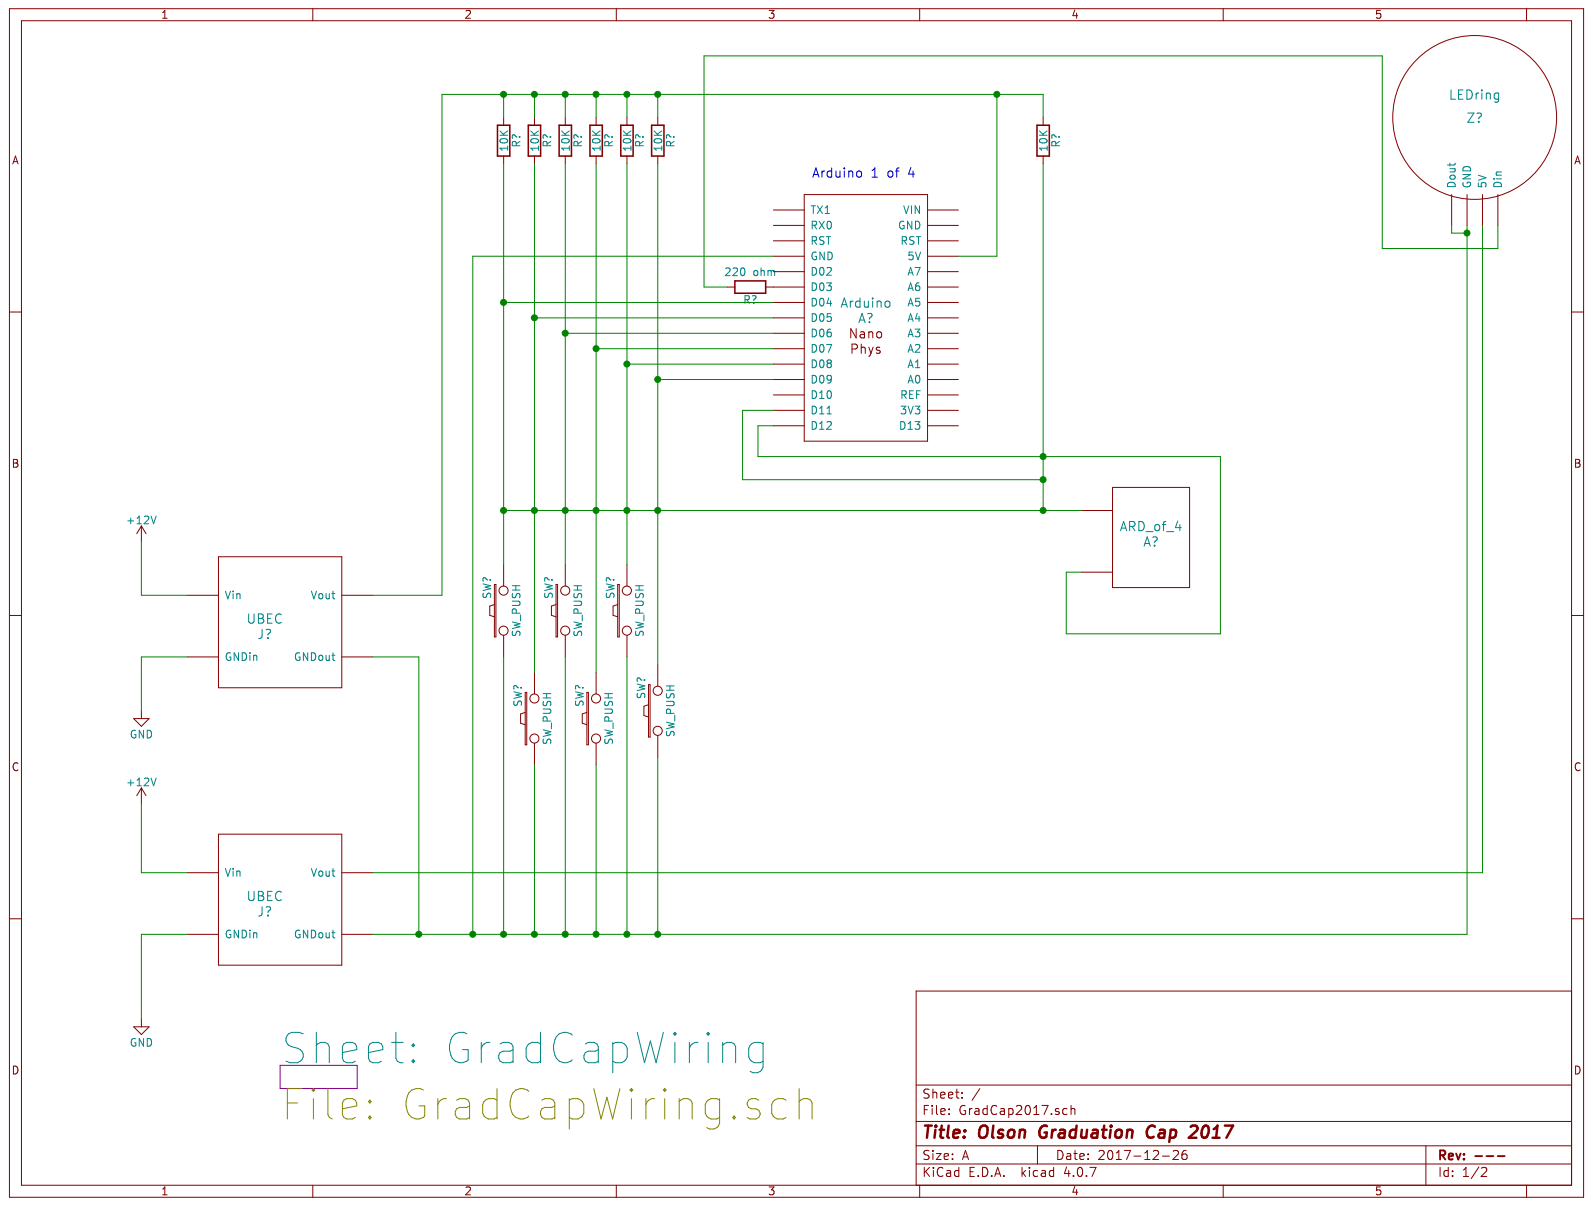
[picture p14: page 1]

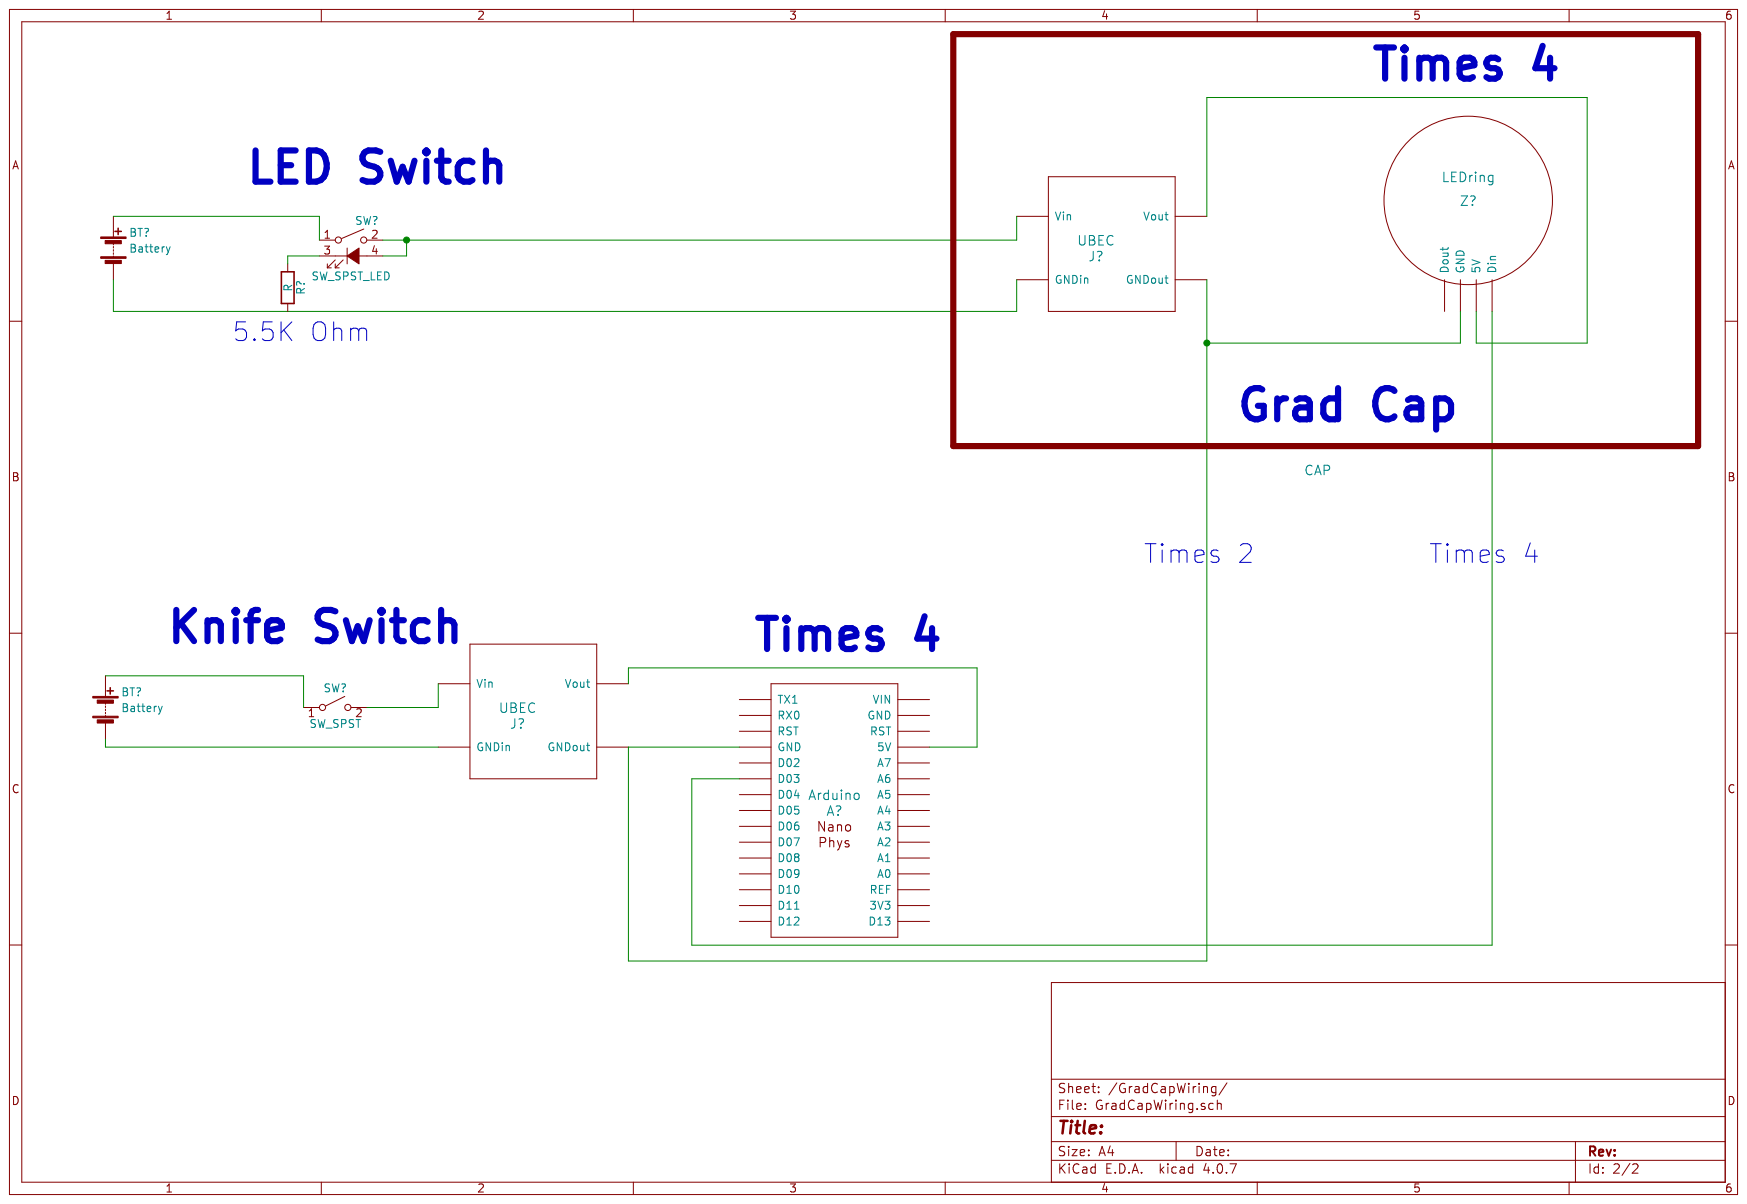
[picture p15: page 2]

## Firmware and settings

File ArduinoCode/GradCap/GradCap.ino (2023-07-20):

#include "FastLED.h"

// Mark Olson 2017-12
//
// major kudos to Daniel Garcia and Mark Kriegsman for the FANTASTIC FastLED library and examples!!!
//
// I am using an Arduino Nano with a USB mini-B connector
//   example: http://www.ebay.com/itm/Nano-V3-0-ATmega328P-5V-16M-CH340-Compatible-to-Arduino-Nano-V3-Without-Cable/201804111413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
//            V3.0 ATmega328P 5V 16M CH340 Compatible to Arduino Nano V3
//            32Kbyte Flash (program storage), 2Kbyte SRAM, 1Kbyte EEPROM
//            http://www.mouser.com/pdfdocs/Gravitech_Arduino_Nano3_0.pdf
//            http://www.pighixxx.com/test/pinouts/boards/nano.pdf
//
// uses Mokungit 93 Leds WS2812B WS2812 5050 RGB LED Ring Lamp Light with Integrated Drivers
//    https://smile.amazon.com/gp/product/B01EUAKLT0/ref=oh_aui_detailpage_o01_s00?ie=UTF8&psc=1
//
// Here is a (somewhat) spec on the 2812b LEDs: https://cdn-shop.adafruit.com/datasheets/WS2812B.pdf
// Here is a Worldsemi WS2812B document for download: http://www.world-semi.com/solution/list-4-1.html#108
//
// Kudos to Daniel Garcia and Mark Kriegsman for the FANTASTIC Arduino FastLED library and examples!!!
//    https://github.com/FastLED/FastLED
//    https://github.com/FastLED/FastLED/blob/master/examples/Fire2012WithPalette/Fire2012WithPalette.ino
//
// The Arduino pattern code here is pretty much done from scratch by me using the FastLED library.
//    I also tried a few items from Mark Kriegsman's classic DemoReel100.ino https://github.com/FastLED/FastLED/tree/master/examples/DemoReel100
//    Okay, I succumbed and added in Mark's beautiful Fire2012withPalette https://github.com/FastLED/FastLED/tree/master/examples/Fire2012WithPalette
// At this point the patterns are about 50-50 mine and Mark Kriegsman
//
// These LEDs use power that adds up. Can use this to estimate the power
//   http://fastled.io/docs/3.1/group___power.html
//     calculate_max_brightness_for_power_vmA(lots of parameters)
//   https://github.com/FastLED/FastLED/blob/master/power_mgt.cpp
//     static const uint8_t gRed_mW   = 16 * 5; // 16mA @ 5v = 80mW
//     static const uint8_t gGreen_mW = 11 * 5; // 11mA @ 5v = 55mW
//     static const uint8_t gBlue_mW  = 15 * 5; // 15mA @ 5v = 75mW
//     static const uint8_t gDark_mW  =  1 * 5; //  1mA @ 5v =  5mW
//   about 42 milliamps per LED at max brightness WHITE
//
// Calculating wire size (Google for instance wire gauge ampacity 5v dc):
//    https://electronics.stackexchange.com/questions/148648/minimum-wire-gauge-for-5-volt-5-amp-system
//
// connections:
//    Data Pin 3 is used for serial communications with the LEDs
//    Data Pins 4-9 are used for pushbuttons 1-6 to choose pattern. Pattern 1 is OFF
//       NOTE: only data pins 4-6 (pushbuttons 1-3) are wired at this time
//    Data Pins 11-12 are used for synchronizing with the other Arduinos. 11 is "IAMSYNC"; 12 is "ALLSYNC" input
// 
// Recommendations -  ;^) I never do the capacitor or the resistor, it still works. Also my wires were about 3 feet!!!
//    Before connecting the WS2812 to a power source, connect a big capacitor from power to ground.
//      A cap between 100microF and 1000microF should be good. Try to place this cap as close to your WS2812 as possible.
//      Electrolytic Decoupling Capacitors 
//    Placing a small-ish resistor between your Arduino's data output and the WS2812's data input will help protect the data pin. A resistor between 220 and 470 O should do nicely. Try to place the resistor as close to the WS2812 as possible.
//    Keep Wires Short!
//    https://github.com/FastLED/FastLED/wiki/Wiring-leds
//

#define WHICH_ARDUINO 0 // this will identify the Arduinos, 0-3 inclusive
#define NUM_ARDUINOS  4 // number of Arduinos is 4; max usable is 3

// with REAL_BUTTONS, holding button down gives pattern 1 which is OFF
// pressing and releasing button 1 gives pattern 2, etc.
#define REAL_BUTTONS 1 // 1 = use buttons for input, 0 = use serial port
#if 0 == REAL_BUTTONS
#define SERIALPORT 1 // use serial port
#endif // not REAL_BUTTONS
#define NO_BUTTON_PRESS -1 // when no input from user
#define NO_BUTTON_CHANGE -1 // when no CHANGE in input from user

static uint32_t button_time = 0;

#include "GradCap.h"

static CRGB led_effect_save_LEDs[EFFECT_NUM_LED_SAV+1];  // place to save original values of effect LEDs. Currently only effect is surround
static int8_t led_effect_varmem[EFFECT_NUM_PROGMEM_SAV]; // place to copy bytes of effect into (from PROGMEM). Currently only effect is surround

#define DO_FIRE_2012 1 // trying to put the Fire2012 demo in and make it look flashy

// buttons:
//   btn1 = knife switch side outer, high
//   btn2 = knife switch side outer, low
//   btn3 = knife switch side inner, low
//   btn4-btn6 - not wired
// patterns:
//   1 = OFF
//   2 = draw then down the drain
//   3 = Radar POLY 2018
//   4 = POLY 2018
//   5 = draw rings
//   6 = do surrounding around letter then fade one to the other
//   7 = rainbowWithGlitter Demo Reel 100 pattern
//   8 = bpm; this is the best Demo Reel 100 pattern on the Mokungit 93 LED disk
//   9 = juggle Demo Reel 100 pattern
//  10 = Fire2012 from another Kriegsman FastLED example
#define MIN_FASTLED_PATTERN 7
static int16_t ButtonsToPatternNumber[] = { NO_BUTTON_PRESS, /*1*/ 2, /*2*/ 3, /*1&2*/ 8, /*3*/ 5, /*1&3*/ 10, /*2&3*/ 9, /*1&2&3*/ 1 };

static int16_t  ptrn_delay = 100; // proper delay for Mark's patterns
static int16_t  ptrn_delay_fastled = 15; // proper delay for FastLED patterns

static int8_t   pattern = 1;
static int8_t   oldPattern = 2;
static int8_t   nextPattern = 2;
static uint16_t bigCount;  // unsigned 16-bit int
static uint8_t  smallCount;  // unsigned  8-bit int
static int8_t   ltr_ptr_idx = -1;
static int8_t   this_effect_ptr_idx = -1;
static int8_t   count_of_ltr_ptr = -1;
static int8_t   count_of_this_effect_ptr = -1;
static int8_t   ptrn_token_array_ptr_idx = -1;
static int8_t * this_effect_ptr = &led_effect_varmem[0];
static int8_t   this_ring = 0; // from ring_6 (value 0, outer ring) to ring_1 (value 5, inner ring (one LED)
static int8_t   this_qrtr = 0; // from qrtr_1 (value 0) to qrtr_4 (value 3), count modulo in either direction
static uint32_t radar_xray_bitmask[(NUM_LEDS_PER_DISK+31)/32] = {0, 0, 0};  // bitmask where X-Ray LEDs are for STEP2_RADAR_XRAY_SHDW1; >= one bit per LED per ring
static uint32_t bitmsk32; // used to pick out the bit in radar_xray_bitmask
static uint8_t  idx_bitmsk32; // index to which array member for radar_xray_bitmask

uint8_t gHue = 0; // rotating "base color" used by Demo Reel 100
CRGBPalette16 gPal; // palette for Fire2012WithPalette()
uint16_t gSeed = ((uint16_t) (WHICH_ARDUINO+1))*((uint16_t) 42); // my favorite is 47 but the whole world loves 42 and HHG2TG
CRGB dark_color_palette[NUM_ARDUINOS]  = { CRGB::DarkGreen, CRGB::Red,    CRGB::Blue, CRGB::DarkOrange };
CRGB light_color_palette[NUM_ARDUINOS] = { CRGB::LimeGreen, CRGB::Yellow, CRGB::Aqua, CRGB::Gold };


// ******************************** SETUP ********************************
// setup()
//   initializes FastLED library for our config
//   initializes push button pins
//   initializes serial port
void setup() {
  delay(100); // for debugging & show
  
  FastLED.addLeds<NEOPIXEL,LED_DATA_PIN>(led_display, NUM_LEDS_PER_DISK);
  FastLED.setBrightness(BRIGHTMAX); // we will do our own power management

  // initialize the input pins. Not sure if my Nano actually has a pullup...
  //    fortunately the PurseHanger controller board has a 10K pullup
  // README - this code assumes these are contiguous and in order
  for (int16_t thePin = PSHBTN1; thePin <= PSHBTN6; thePin ++) {
    pinMode(thePin, INPUT_PULLUP);
  } // end initialize pushbutton input pins
  
  // now the ALLSYNC input pin
  pinMode(ALLSYNC, INPUT_PULLUP);
  // and the IAMSYNC output pin
  pinMode(IAMSYNC, INPUT_PULLUP);

  setMySync(0); // we are not yet in synch

#if (DEBUG+SERIALPORT)
  // README if debugging we want serial port
  Serial.begin(9600);
  Serial.println(F("setup grad cap"));
#endif // DEBUG

  smallCount = 0;
  bigCount = 0;

  // initialize gPal for Fire2012WithPalette()
  gPal = CRGBPalette16( CRGB::Black, dark_color_palette[WHICH_ARDUINO], light_color_palette[WHICH_ARDUINO], CRGB::White);
  // initialize random seed to be different for each Arduino
  random16_set_seed (gSeed);

  pattern = 1; // FIXME - set to 1 when read pattern from buttons
  oldPattern = NO_BUTTON_CHANGE;
  nextPattern = NO_BUTTON_CHANGE;
} // end setup()

// ******************************** LOOP ********************************
void loop() {
  gHue += (WHICH_ARDUINO*2 + 1); // rotating "base color" used by Demo Reel 100
  nextPatternFromButtons();
  if ((NO_BUTTON_CHANGE != nextPattern) && (nextPattern != pattern)) {
    pattern = nextPattern;
  }
  nextPattern = NO_BUTTON_CHANGE;
  if (oldPattern != pattern) {
    Serial.print(F("switch to pattern ")); Serial.println((int16_t) pattern);
  }
  checkDataGuard();
  doPattern();
  checkDataGuard();
  FastLED.show();
  oldPattern = pattern;

  if (pattern < MIN_FASTLED_PATTERN) { // Mark's patterns
    doDwell(ptrn_delay, 1);
  } else { // FastLED patterns
    doDwell(ptrn_delay_fastled, 1);
  }

  smallCount += 1;
  bigCount += 1;
  if (smallCount > 9) smallCount = 0;
} // end loop()

// ******************************** UTILITIES ********************************



// doPattern()
//   first level organization of patterns for show, checking for button presses
//   keeps track of oldPattern and nextPattern
//   Calls: int16_t doPatternDraw(int16_t led_delay, const int8_t * ltr_ptr, const int8_t * ptrn_token_array_ptr, CRGB foreground, CRGB background, CRGB blinking, uint32_t parm1, uint32_t parm2, uint32_t parm3);
//
void doPattern() {
  static int16_t save_return = 0;
  static int16_t dwell = 500;

  switch (pattern) {
    case 1: // 1 = OFF
       save_return = doPatternDraw(10, ltrs_Poly, ptrnOff, CRGB::Gold, CRGB::Blue, CRGB::Green, 0, 0, 0);
       LED_DISPLAY(TARGET_DSPLAY+NUM_LEDS_PER_DISK-1)
       led_display[TARGET_DSPLAY+NUM_LEDS_PER_DISK-1] = CRGB::Red; // indication that we are on
       // DEBUG2_RETURN(save_return, __LINE__)
       break;
    case 2: // 2 = draw then down the drain
    default:
       save_return = doPatternDraw(10, ltrs_Poly, ptrnJustWideDraw, CRGB::Gold, CRGB::Blue, CRGB::Green, 0, 0, 0);
       // DEBUG2_RETURN(save_return, __LINE__);
       save_return = doPatternDraw(10, ltrs_Poly, ptrnCopyToShdw1, CRGB::Gold, CRGB::Blue, CRGB::Green, 0, 0, 0);
       // DEBUG2_RETURN(save_return, __LINE__)
       if (doDwell(dwell, 200)) break;
       save_return = doPatternDraw(10, ltrs_Poly, ptrnDownTheDrain, CRGB::Gold, CRGB::Blue, CRGB::Green, 0, 0, 0);
       // DEBUG2_RETURN(save_return, __LINE__)
       save_return = doPatternDraw(10, ltrs_Poly, ptrnDownTheDrainIn, CRGB::Gold, CRGB::Blue, CRGB::Green, 0, 0, 0);
       // DEBUG2_RETURN(save_return, __LINE__)
       if (doDwell(dwell, 200)) break;
       save_return = doPatternDraw(10, ltrs_Poly, ptrnUpTheDrain, CRGB::Gold, CRGB::Blue, CRGB::Green, 0, 0, 0);
       // DEBUG2_RETURN(save_return, __LINE__);
       save_return = doPatternDraw(10, ltrs_Poly, ptrnUpTheDrainIn, CRGB::Gold, CRGB::Blue, CRGB::Green, 0, 0, 0);
       // DEBUG2_RETURN(save_return, __LINE__);
       if (doDwell(dwell, 200)) break;
       save_return = doPatternDraw(10, ltrs_2018, ptrnJustWideDraw, CRGB::Gold, CRGB::Blue, CRGB::Green, 0, 0, 0);
       // DEBUG2_RETURN(save_return, __LINE__);
       save_return = doPatternDraw(10, ltrs_2018, ptrnHaunted, CRGB::Gold, CRGB::Blue, CRGB::Green, 0, 0, 0);
       // DEBUG2_RETURN(save_return, __LINE__);
       if (doDwell(dwell, 1)) break;
       break;
    case 3: // 3 = Radar
       save_return = doPatternDraw(1, ltrs_Poly, ptrnJustWideDraw, CRGB::Gold, CRGB::Blue, CRGB::Green, 0, 0, 0);
       if (doDwell(dwell, 1)) break;
       // DEBUG2_RETURN(save_return, __LINE__)
       save_return = doPatternDraw(1, ltrs_Poly, ptrnCopyToShdw1, CRGB::Gold, CRGB::Blue, CRGB::Green, 0, 0, 0);
       if (doDwell(1, 1)) break;
       // DEBUG2_RETURN(save_return, __LINE__)
       for (uint8_t tmp = 0; (tmp < 2) ; tmp++) {
         save_return = doPatternDraw(100, ltrs_Poly, ptrnRadarFrgndFromShdw1, CRGB::Gold, CRGB::Blue, CRGB::Green, 0, 0, 0);
         // DEBUG2_RETURN(save_return, __LINE__)
       } // end loop
       save_return = doPatternDraw(1, ltrs_2018, ptrnJustWideDraw, CRGB::Gold, CRGB::Blue, CRGB::Green, 0, 0, 0);
       if (doDwell(dwell, 1)) break;
       // DEBUG2_RETURN(save_return, __LINE__)
       save_return = doPatternDraw(1, ltrs_2018, ptrnCopyToShdw1, CRGB::Gold, CRGB::Blue, CRGB::Green, 0, 0, 0);
       if (doDwell(1, 1)) break;
       // DEBUG2_RETURN(save_return, __LINE__)
       for (uint8_t tmp = 0; (tmp < 2) ; tmp++) {
         save_return = doPatternDraw(100, ltrs_2018, ptrnRadarFrgndFromShdw1, CRGB::Gold, CRGB::Blue, CRGB::Green, 0, 0, 0);
         // DEBUG2_RETURN(save_return, __LINE__)
       } // end loop
       break;
    case 4: // 4 = POLY 2018
       save_return = doPatternDraw(8, ltrs_Poly, ptrnWideDraw, CRGB::Gold, CRGB::Blue, CRGB::Green, 0, 0, 0);
       // DEBUG2_RETURN(save_return, __LINE__)
       if (doDwell(dwell, 1)) break;
       save_return = doPatternDraw(8, ltrs_2018, ptrnWideDraw, CRGB::Gold, CRGB::Blue, CRGB::Green, 0, 0, 0);
       // DEBUG2_RETURN(save_return, __LINE__)
       if (doDwell(dwell, 1)) break;
       break;
    case 5: // 5 = draw rings
       // save_return = doPatternDraw(10, ltrs_Poly, ptrnWide, CRGB::Gold, CRGB::Blue, CRGB::Green, 0, 0, 0);
       save_return = doPatternDraw(100, ltrs_Poly, ptrnRingDraw, CRGB::Red, CRGB::Blue, CRGB::Green, 0, 0, 0);
       // DEBUG2_RETURN(save_return, __LINE__)
       save_return = doPatternDraw(100, ltrs_Poly, ptrnRingQrtrDraw, CRGB::Red, CRGB::Blue, CRGB::Green, 0, 0, 0);
       // DEBUG2_RETURN(save_return, __LINE__)
       // save_return = doPatternDraw(1000, ltrs_Poly, 5, CRGB::Red, CRGB::Blue, CRGB::Green, 0, 0, 0);
       doDwell(dwell, 1);
       break;
    case 6: // 6 = do surrounding around letter then fade one to the other
       if (oldPattern != pattern) {
         save_return = doPatternDraw(8, ltrs_Poly, ptrnDblClkws, CRGB::Gold, CRGB::Blue, CRGB::Green, 0, 0, 0);
         // DEBUG2_RETURN(save_return, __LINE__)
         save_return = doPatternDraw(8, ltrs_2018, ptrnWideDrawShdw1Fade, CRGB::Green, CRGB::Gold, CRGB::Blue, 0, 0, 0);
         // DEBUG2_RETURN(save_return, __LINE__)
       }
       break;
    case 7:
       rainbowWithGlitter();
       break;
    case 8: // this is the best one on the Mokungit 93 LED disk
       bpm();
       break;
    case 9:
       juggle();
       break;
    case 10:
#if DO_FIRE_2012
       Fire2012WithPalette();
#else
       juggle();
#endif
       break;
  } // end switch on pattern
  if (pattern != oldPattern) {
    oldPattern = pattern;
  } // end if pattern changed
} // end doPattern()

void rainbow() { // pattern from Demo Reel 100
  // FastLED's built-in rainbow generator
  fill_rainbow( led_display, NUM_LEDS_PER_DISK, gHue, 7+WHICH_ARDUINO);
}

void rainbowWithGlitter() { // pattern from Demo Reel 100
  // built-in FastLED rainbow, plus some random sparkly glitter
  rainbow();
  addGlitter(80+(WHICH_ARDUINO-1)*20);
} // end rainbowWithGlitter

void addGlitter( fract8 chanceOfGlitter) { // helper routine from Demo Reel 100
  if( random8() < chanceOfGlitter) {
    led_display[ random16(NUM_LEDS_PER_DISK) ] += CRGB::White;
  }
} // end 

void confetti() { // pattern from Demo Reel 100
  // random colored speckles that blink in and fade smoothly
  fadeToBlackBy( led_display, NUM_LEDS_PER_DISK, (WHICH_ARDUINO+1)*10);
  int pos = random16(NUM_LEDS_PER_DISK);
  led_display[pos] += CHSV( gHue + random8(64), 200, 255);
} // end 

void bpm() { // pattern from Demo Reel 100
  // colored stripes pulsing at a defined Beats-Per-Minute (BPM)
  uint8_t BeatsPerMinute = 62+(WHICH_ARDUINO-1)*10;
  CRGBPalette16 palette = PartyColors_p;
  uint8_t beat = beatsin8( BeatsPerMinute, 64, 255);
  for( int i = 0; i < NUM_LEDS_PER_DISK; i++) { //9948
    led_display[i] = ColorFromPalette(palette, gHue+(i*2), beat-gHue+(i*10));
  }
} // end bpm()

void juggle() { // pattern from Demo Reel 100
  // eight colored dots, weaving in and out of sync with each other
  fadeToBlackBy( led_display, NUM_LEDS_PER_DISK, (WHICH_ARDUINO+1)*20);
  byte dothue = 0;
  for( int i = 0; i < 8; i++) {
    led_display[beatsin16(i+7,0,NUM_LEDS_PER_DISK)] |= CHSV(dothue, 200, 255);
    dothue += 32;
  }
} // end juggle()

// ******************************** SYNCHRONIZATION UTILITIES ********************************

// setMySync(val) - sets sync to TRUE if val is nonzero, else sets sync to FALSE
void setMySync(uint8_t yes) {
  if (0 == yes) {
    digitalWrite(IAMSYNC, LOW); // sync = FALSE
  } else {
    digitalWrite(IAMSYNC, HIGH); // sync = TRUE
  }
} // end setMySync()

// val = areWeAllSync() - returns nonzero if we are all sync
int8_t areWeAllSync() {
  int8_t val = digitalRead(ALLSYNC);
  if (LOW == val) return(0);
  else            return(1);
} // end areWeAllSync()

// val = iamSyncAreWeAllSync - sets our sync output TRUE and returns nonzero if we are all sync
int8_t iamSyncAreWeAllSync() {
  iamSync(); // set us as synchronized
  return(areWeAllSync()); // return 1 if we are now all synchronized
} // end iamSyncAreWeAllSync()


// ******************************** EFFECT UTILITIES ********************************

//    NOTE: now all LEDs have a surround effect, but it is in PROGMEM. It was copied into local storage at effect_LEDidx_array_ptr
void saveSurroundEffectLEDs(int8_t ltr_index, const int8_t * effect_LEDidx_array_ptr, int16_t draw_target, CRGB * save_here) {
  LED_DISPLAY(draw_target + ltr_index)
  save_here[0] =   led_display[draw_target + ltr_index]; // save_here[0] is the LED in the middle, [1..end] are the LEDs in the surround effect
  for (uint8_t i = 1; i <= -effect_LEDidx_array_ptr[0]; i++) {
    LED_DISPLAY(draw_target + effect_LEDidx_array_ptr[i])
    save_here[i] = led_display[draw_target + effect_LEDidx_array_ptr[i]];
  } // end save the original LED info for surround effect area
} // end saveSurroundEffectLEDs()

CRGB calcColor_step2DawClrMax(int8_t thePtrnToken, int8_t tokenSmallest, CRGB blinking, CRGB foreground, CRGB background) {
  CRGB theColor;
  switch ((thePtrnToken - tokenSmallest) % TOKEN_DRAW_CLR_MAX) {
    case TOKEN_DRAW_CLR_BLNKNG:
      theColor = blinking;
      break;
    case TOKEN_DRAW_CLR_BLACK:
    default:
      theColor = CRGB::Black ;
      break;
    case TOKEN_DRAW_CLR_FRGND:
      theColor = foreground;
      break;
    case TOKEN_DRAW_CLR_BKGND:
      theColor = background;
      break;
  }
  return(theColor);
} // end calcColor_step2DawClrMax


// ******************************** BUTTON AND TIMING UTILITIES ********************************


// doDwell(int16_t dwell, uint8_t must_be_diff_pattern) - dwell or break out if button press
//   returns TRUE if should switch to different pattern
//   else returns false
//
// keeps track of button_time
//
#define SMALL_DWELL 20
int16_t doDwell(int16_t dwell, uint8_t must_be_diff_pattern) {
  int16_t numloops = dwell / SMALL_DWELL;
  int16_t i;

  for (i = 0; i < numloops; i++) {
    nextPatternFromButtons();
    if ((0 != must_be_diff_pattern) && (nextPattern == pattern)) nextPattern = NO_BUTTON_CHANGE;
    if (nextPattern != NO_BUTTON_CHANGE) return(nextPattern != NO_BUTTON_CHANGE);
    delay(SMALL_DWELL);
    button_time += SMALL_DWELL;
  }
  if ((dwell % SMALL_DWELL) != 0) {
    nextPatternFromButtons();
    if ((0 != must_be_diff_pattern) && (nextPattern == pattern)) nextPattern = NO_BUTTON_CHANGE;
    if (nextPattern != NO_BUTTON_CHANGE) return(nextPattern != NO_BUTTON_CHANGE);
    delay(dwell % SMALL_DWELL);
    button_time += (dwell % SMALL_DWELL);
  }
  return(nextPattern != NO_BUTTON_CHANGE);
} // end doDwell()

// doPtrnShowDwell() - break out if button press, then show, then dwell
// Used inside doPatternDraw
// Idea is to not do delays when drawing to target that is not visible
// Two things that matter: value returned and timing
//   value returned:
//     returns TRUE if should switch to different pattern
//     else returns false
//   timing:
//     if draw_target is TARGET_DSPLAY (visible display LEDs), either does entire delay or delays until button press
//     if draw_target is not TARGET_DSPLAY, returns immediately after checking for button press
int16_t doPtrnShowDwell(int16_t draw_target, int16_t dwell, int16_t called_from) {
  nextPatternFromButtons();
  DEBUG2_PRINT(F("doPtrnShowDwell called from: "))
  DEBUG2_PRINT((int16_t) called_from)
  DEBUG2_PRINT(F(" pattern: "))
  DEBUG2_PRINT((int16_t) pattern)
  DEBUG2_PRINT(F(" nextPattern: "))
  DEBUG2_PRINT((int16_t) nextPattern)
  DEBUG2_PRINT(F(" draw_target: "))
  DEBUG2_PRINTLN((int16_t) draw_target)
  if (nextPattern == pattern) nextPattern = NO_BUTTON_CHANGE;
  if ((nextPattern != pattern) && ( nextPattern != NO_BUTTON_CHANGE)) {
    DEBUG2_PRINTLN(F("  doPtrnShowDwell rtn; pattern != nextPattern"))
    return(nextPattern != NO_BUTTON_CHANGE);
  }
  if (draw_target != TARGET_DSPLAY) {
    DEBUG2_PRINTLN(F("  doPtrnShowDwell rtn; draw_target != TARGET_DSPLAY"))
    return(nextPattern != NO_BUTTON_CHANGE);
  }
  DEBUG2_PRINTLN(F("  FastLED.show()"))
  FastLED.show();
  return(doDwell(dwell, 1));
} // end doPtrnShowDwell()

// getButtonPress() - get next button press, true button or debugging
int16_t getButtonPress() {
#if REAL_BUTTONS
  return(checkButtons());
#else // end if REAL_BUTTONS; now NOT REAL_BUTTONS
  return(checkKeyboard());
#endif // not REAL_BUTTONS
} // end getButtonPress()
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

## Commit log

2017-12-10 basics of design
    [GraduationCapDesign_2017.xlsx]
2017-12-11 initial version of 3D print files
    [GradCapBracket.scad, roundCornersCube.scad]
2017-12-11 add calculations and dimensions
    [GraduationCapDesign_2017.xlsx]
2017-12-11 add more features
    [GradCapBracket.scad]
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2017-12-29 information on power and batteries
    [GraduationCapDesign_2017.xlsx]
2017-12-29 latest expt data
    [GraduationCapDesign_2017.xlsx]
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2017-12-31 Schematic for just one Arduino
    includes physical Arduino pin configuration
    [GradCap2017.kicad_pcb, GradCap2017.sch]
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2018-01-01 add buttons
    [GradCap2017.sch]
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2018-01-05 LED layout updates
    [GraduationCapDesign_2017.xlsx]
2018-01-07 updates testing on physical board
    [GraduationCapDesign_2017.xlsx]
2018-01-13 some new letters for POLY 2018
    [GraduationCapDesign_2017.xlsx]
2018-01-14 method to mark adjacent cells
    [GraduationCapDesign_2017.xlsx]
2018-01-14 be consistent about starting point and direction
    [GraduationCapDesign_2017.xlsm]
2018-01-14 build up the effect string
    [GraduationCapDesign_2017.xlsm]
2018-01-14 new surround LEDs
    [GraduationCapDesign_2017.xlsm]
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2018-01-19 redesign pattern_04
    [GraduationCapDesign_2017.xlsm]
2018-01-20 complete rewrite of pattern 4
    [GraduationCapDesign_2017.xlsm]
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2018-01-20 fix bug letter indices, do pattern seq = 5
    [GradCap.h, GradCap.ino]
2018-01-20 fix bug letter indices
    [GraduationCapDesign_2017.xlsm]
2018-01-21 start of ring draw and shadow capabilities
    [GraduationCapDesign_2017.xlsm]
2018-01-21 starting to get DRAW_RING to work
    [GraduationCapDesign_2017.xlsm]
2018-01-22 still some issue with drawing ring 1 (outer)
    [GraduationCapDesign_2017.xlsm]
2018-01-26 fix the index problem
    [GradCap.ino]
2018-01-28 fade disk to shadow1 works but surround calcs in shadow not working
    [GradCap.ino]
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2018-01-29 fixed button processing problem and adjusted timing for no debug messages
    [GradCap.ino]
2018-02-02 fix NUM_LEDS vs NUM_LEDS_PER_DISK
    [GradCap.ino]
2018-02-02 rework comments; still some bug with shadow or fading to shadow
    [GradCap.ino]
2018-02-02 fixed at least some of the shadow bugs
    [GradCap.ino]
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2018-02-03 move some consts into PROGMEM
    [GraduationCapDesign_2017.xlsm]
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2018-02-04 need four Arduinos
    [GradCap2017.sch]
2018-02-04 add simple radar pattern
    [GraduationCapDesign_2017.xlsm]
2018-02-05 make radar fade a little more like a radar display
    [GraduationCapDesign_2017.xlsm]
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2018-02-16 helpful utility to balance parenthesis
    [paren_balance.xlsx]
2018-02-17 some more advanced radar calcs checkout
    [RadarAdvancedCalcs.xlsx]
2018-02-18 make it easier to update RadarAdvancedCalcs.xlsx
    [RadarAdvancedCalcs.xlsx]
2018-03-03 small changes; also add info on wiring LED Disk
    [GraduationCapDesign_2017.xlsm]
2018-03-03 minor changes plus Purse Hanger
    [GradCapPurseHanger2.scad, GraduationCapDesign_2017.xlsm]
2018-03-10 start to add some array debugging
    [GraduationCapDesign_2017.xlsm]
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2018-03-12 more array bounds checking, but bug was weak battery to LEDs coupling across ground lines
    [GradCap.ino]
2018-03-15 latest updates
    [GraduationCapDesign_2017.xlsm, paren_balance.xlsx]
2018-03-19 latest 3D print files
    [GradCapBracket.scad, GradCapPurseHanger.scad]
2018-03-20 add one button
    [GradCapPurseHanger.scad]
2018-03-24 some renaming and 180 flip
    [GradCapBracket.scad]
2018-03-24 using less complicated version
    [GradCapPurseHanger2.scad]
2018-03-25 getting ready to turn the mounting pins into pinholes
    [GradCapBracket.scad]
2018-03-25 change the pins into holes for inserting pins
    [GradCapBracket.scad]
2018-03-25 test for button cutout
    [GradCapPurseHanger.scad]
2018-03-30 button cutout works
    [GradCapPurseHanger.scad]
2018-04-08 change to holes with cable-tie attach and add all six buttons
    [GradCapPurseHanger.scad]
2018-04-08 keystone files for RJ45
    [Dimensions.xlsx, keystone_mdo.scad]
2018-04-15 adding more definition of button holes and keystone jack holder
    [GradCapPurseHanger.scad]
2018-04-15 start rounding off keystone jack holder
    [keystone_mdo.scad]
2018-04-15 pretty good rounding off
    [keystone_mdo.scad]
2018-04-15 documenting hooks - historical approach - not practical given purse size versus 3D printer size
    [GradCapPurseHanger.scad]
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2018-04-16 add data wire holes
    [GradCapPurseHanger.scad]
2018-04-21 latest rounded RJ45 connector
    [GradCapPurseHanger.scad]
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2018-04-30 slot for attachment to purse hanger
    [keystone_mdo.scad]
2018-04-30 slightly smaller and rotated 90 deg for printing
    [GradCapPurseHanger.scad]
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2018-05-02 move buttons and make more room
    [GradCapPurseHanger.scad]
2018-05-02 add arduino/ubec models and holes
    [GradCapPurseHanger.scad]
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2018-05-04 add knife switch and rocker mount
    [GradCapPurseHanger.scad]
2018-05-04 change expression order and add some module comments; add generic thru-hole module
    [GradCapPurseHanger.scad]
2018-05-05 add knife switch holes
    [GradCapPurseHanger.scad]
2018-05-05 add resistor and start adding wire attachments
    [GradCapPurseHanger.scad]
2018-05-05 add through-holes for wire attachments
    [GradCapPurseHanger.scad]
2018-05-05 might be final version
    [GradCapPurseHanger.scad]
2018-05-05 might be final version again
    [GradCapPurseHanger.scad]
2018-05-06 3D printer failure - that doesn't look goodgit status!
2018-05-06 3D printer failure - that doesn't look good\!\!\!
2018-05-07 cutout for knife switch stability
    [GradCapPurseHanger.scad]
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2018-05-20 in process for reworking REAL_BUTTONS code
    [GradCap.h, GradCap.ino]
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2018-05-22 error for Arduino power routing
2018-05-25 add wiring diagram to schematic
    [GradCap2017.sch]
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2018-05-27 add STL file for Purse Hanger (controller board)
    [GradCapPurseHanger.stl]
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2018-05-30 swap 0 and 3
    [GradCap.h]
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2018-05-31 remove old keystone RJ45 stuff - no room for it
    [Dimensions.xlsx, keystone_mdo.scad]
2018-05-31 remove Mokungit bracket for simplification
    [GradCapBracket.scad]
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2018-06-08 show mapping of arduinos to LED disks on cap
    [GraduationCapDesign_2017.xlsm]
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2019-08-31 re-organize and add final images
    [GradCapBracket.stl, MdoRoundIt.scad, aaaTest.stl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]
2019-08-31 continue re-organization with buildInfo
    [RadarAdvancedCalcs.xlsx]
